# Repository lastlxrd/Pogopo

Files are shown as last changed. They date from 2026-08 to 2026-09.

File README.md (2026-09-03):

# Pogopo

*Both Pogopo and PogopoOS are still in the early stages of development.*

[@lastlxrd](https://github.com/lastlxrd) 2026

<p align="center">
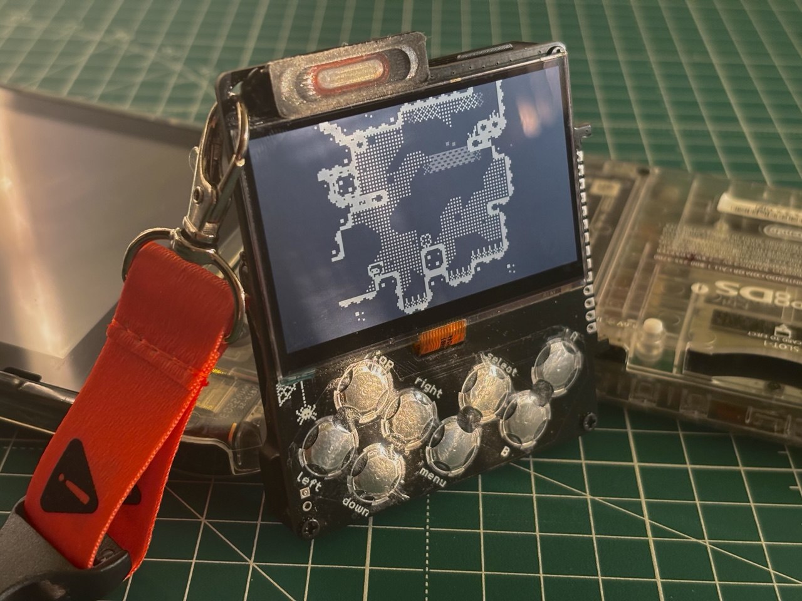
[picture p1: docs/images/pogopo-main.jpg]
Pogopo handheld console
  
</p>

<p align="center">
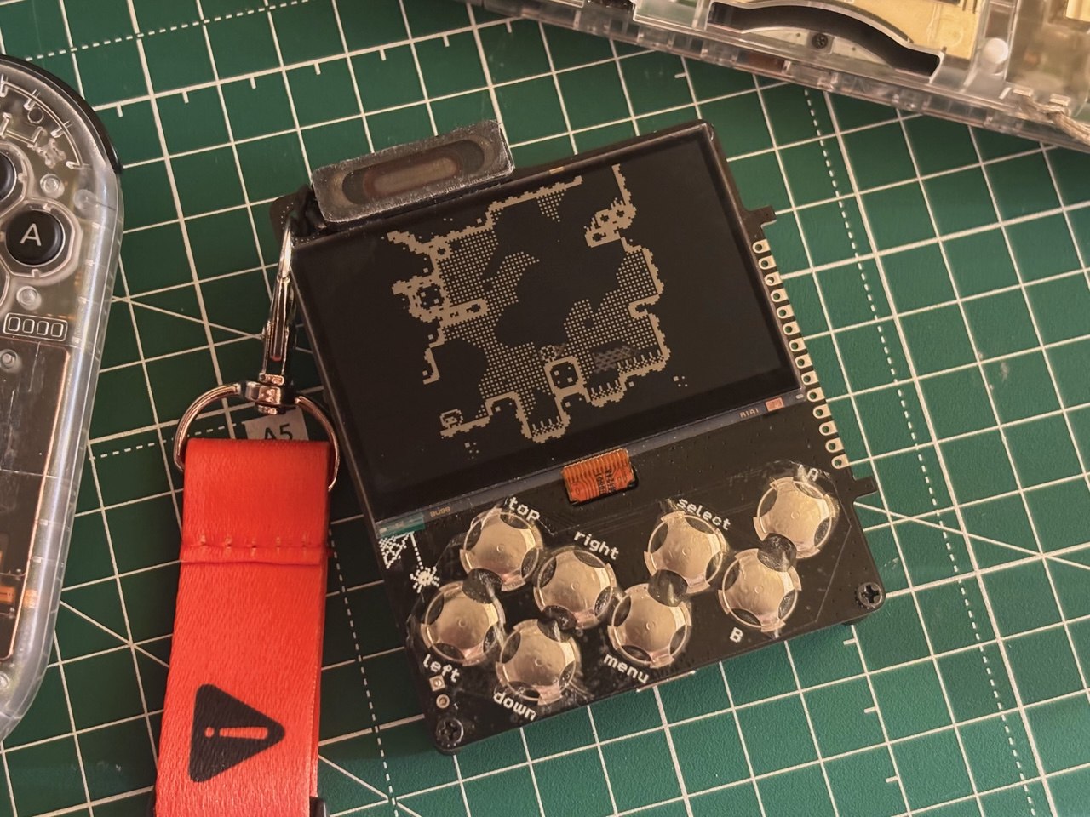
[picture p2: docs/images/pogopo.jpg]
Pogopo top
  
</p>

<p align="center">
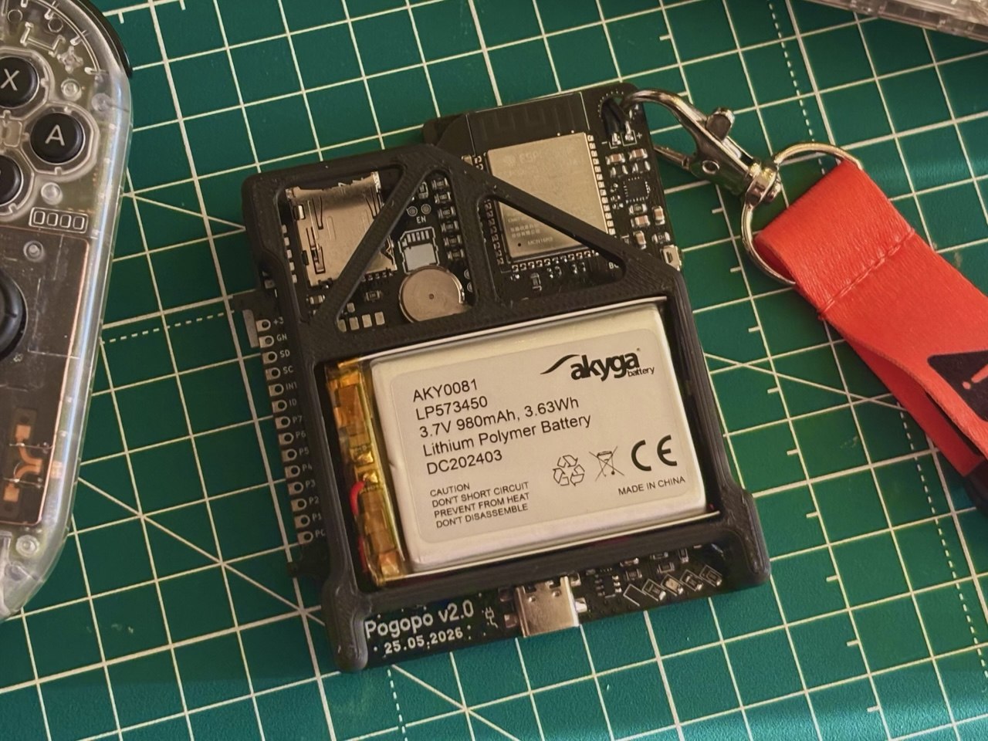
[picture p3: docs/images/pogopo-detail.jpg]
Pogopo hardware detail
  
</p>

## Getting Started

Pogopo is still under active development. More complete documentation will be added as the hardware and software mature.

[Documentation](https://lastlxrd.github.io/Pogopo/)
[FAQ](https://lastlxrd.github.io/Pogopo/faq/)

## Project Summary

Pogopo is a custom hand-built handheld console based on the ESP32-S3. It combines a low-power monochrome display, physical controls, audio, motion sensing, removable storage, haptic feedback, and custom power management in one compact device.

The goal is to create a standalone handheld capable of running native applications, utilities, emulators, and custom games through a simple graphical interface. The current device is a working development prototype, with both its hardware and software continuing to evolve.

## Hardware

- ESP32-S3 with 16 MB flash and 8 MB PSRAM
- Sharp LS027B7DH01 400 × 240 Memory LCD
- BMI270 motion sensor
- MAX98357A I2S audio amplifier
- microSD card over 4-bit SDMMC
- TCA9555 GPIO and button expander
- D-pad, A, B, Menu, Start, and Power controls
- Vibration motor
- Rechargeable battery
- Onboard charging and power management
- Custom PCB and 3D-printed enclosure

## PogopoOS

PogopoOS is the custom operating system and application platform developed specifically for the Pogopo console.

- ESP-IDF-based firmware
- Graphical launcher and application framework
- Reusable display, input, audio, storage, and sensor drivers
- Native I2S audio and WAV playback
- Motion sensing and visualization tools
- microSD file access
- Persistent settings
- Power quick menu and clean LCD shutdown
- Haptic feedback
- Native Game Boy emulation
- Full-speed Game Boy CPU execution
- Approximately 30 FPS LCD presentation
- Four-shade ordered dithering
- Fixed-rate Game Boy audio
- ROM loading from microSD
- Experimental PDX and Lua game runtime

Game ROMs and third-party game files are not included in this repository.

## Development

Pogopo and PogopoOS are developed through small tested milestones. Commit messages contain short summaries of individual changes, while longer technical notes are stored in [`docs/history/`](docs/history/).

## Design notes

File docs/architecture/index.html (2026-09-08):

Skip to content

pogopodocumentation Search docs/ (https://github.com/lastlxrd/Pogopo)

A small, evolving reference for the pogopo hardware and pogopoOS firmware.

System

# Architecture

PogopoOS separates board-specific communication from reusable services and application behavior. The goal is a small set of understandable layers, not documentation for every source file.

## Logical layers

Applications sit at the top of the system and depend on PogopoOS rather than individual chips. The launcher, settings, diagnostics, Game Boy emulator, and PogoDate runtime all enter through the same application lifecycle, so opening an app, suspending it behind the quick menu, and returning Home follow one path.

PogopoOS owns that lifecycle and gives the active application access to graphics, input, audio, storage, motion, haptics, power, and settings. Those services translate useful actions such as reading a button or presenting a frame into driver operations. Pin mappings and bus details remain below the service boundary, where SPI, I²C, I²S, SDMMC, ADC, and GPIO code communicate with the physical board.

This direction is deliberate: an application can use a device capability without reconfiguring the hardware behind it. It also keeps shutdown, save flushing, display clearing, and system overlays under one owner.

## Task and core organization

FreeRTOS work is separated by latency and ownership. The current Game Boy path runs emulation and input on Core 1. Core 0 handles fixed-clock I²S output, decoupled APU generation, motion and power services, VCOM maintenance, and the lower-priority PogopoOS UI/display loop.

This split is a performance decision for the current firmware, not a permanent ABI. Changes are validated with serial timing, underrun, heap, cache, and I²C diagnostics.

## Typical data flow

A button sample begins at the TCA9555, passes through the input service, and reaches only the active application. Drawing moves in the opposite direction: an application writes to the shared 1-bit canvas, then the display driver sends changed rows or a complete frame to the Sharp LCD.

Game Boy audio is generated by MiniGB APU into an internal ring buffer and consumed by a fixed-rate I²S task connected to the MAX98357A. Power-off is coordinated in the same way: the Power service starts the overlay, waits for pending saves, clears the physical display, and only then asks the BQ24295 to enter ship mode.

pogopo documentation ·

## On this page

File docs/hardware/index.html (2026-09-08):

Skip to content

pogopodocumentation Search docs/ (https://github.com/lastlxrd/Pogopo)

A small, evolving reference for the pogopo hardware and pogopoOS firmware.

System

# Hardware

pogopo is built around a custom ESP32-S3 PCB with a 400 × 240 monochrome display, physical controls, audio, storage, motion sensing, haptics, and battery management.

## System overview

The dual-core ESP32-S3 is paired with 16 MB of flash and 8 MB of Octal PSRAM. A Sharp LS027B7DH01 Memory LCD provides the 400 × 240 monochrome display, while a four-bit SDMMC bus connects removable storage without sharing the display’s SPI path.

Front controls arrive through a TCA9555 I/O expander. Motion data comes from a BMI270, audio leaves the MCU over I²S to a MAX98357A amplifier, and a BQ24295 manages charging and the power path. These choices keep the board compact while giving firmware direct control over timing-critical work.

## Core components

### ESP32-S3

The MCU runs PogopoOS, renders the interface, coordinates every peripheral, and hosts the Game Boy and PogoDate runtimes. GPIO, SPI, I²C, I²S, SDMMC, and ADC are all available directly from the chip, while FreeRTOS distributes time-sensitive work across both cores. It was chosen because it combines those interfaces with external-memory support and a mature ESP-IDF stack in one compact part.

### Sharp LS027B7DH01 Memory LCD

The 400 × 240 panel displays the launcher, applications, games, diagnostics, and shutdown animation through SPI2 at 14 MHz. PogopoOS keeps a 12 KB 1-bit framebuffer, transfers only dirty rows when practical, and maintains VCOM in a dedicated task. The panel was chosen for its sharp monochrome image and its ability to retain static pixels without continuous full-screen refresh.

### BMI270

The six-axis IMU reports acceleration and angular rate for diagnostics and motion-aware applications. It shares the I²C bus at address 0x68 and has a dedicated interrupt on GPIO18. This provides a compact motion input without consuming the GPIOs reserved for controls, display, storage, and audio.

### MAX98357A audio

The MAX98357A converts the firmware’s PCM stream into amplified speaker output. DATA, BCLK, and LRCK connect directly to the ESP32-S3 I²S peripheral, and the Game Boy path runs at a fixed 32,768 Hz. A digital amplifier keeps sample timing under firmware control and avoids a separate analog DAC stage.

### microSD storage

The microSD card holds ROMs, audio, Playdate packages, and other user content through ESP-IDF’s FAT filesystem. It uses a four-bit SDMMC connection on D0–D3, CLK, and CMD rather than a basic SPI link. That wider bus improves bulk transfer speed and leaves the display bus independent.

### TCA9555 and controls

The TCA9555 reads the D-pad, A, B, Start, and Menu as one active-low byte over I²C at 0x20, with its interrupt connected to GPIO21. A failed read is treated as a released sample so a bus fault cannot leave a control stuck. The expander saves eight direct MCU pins and lets firmware capture the entire front-panel state in one transaction.

### Haptics

The vibration motor is driven from GPIO3 through the board’s output stage. It gives UI and gameplay actions a short physical response, which is useful when another sound or screen effect would be distracting.

### Battery and power management

The BQ24295 at I²C address 0x6B manages charging and the power path. Firmware reads its charge and fault state, measures the battery through a gated ADC on GPIO1, handles the separate Power input on GPIO17, and requests ship mode only after saves are flushed and the LCD is cleared. This gives PogopoOS a controlled shutdown path instead of relying on an abrupt battery disconnect.

## Custom PCB

The custom board integrates the ESP32-S3, display connection, SDMMC bus, I²C peripherals, digital audio, controls, haptics, and power-management signals used by PogopoOS. Bring-up diagnostics probe the TCA9555, BMI270, and BQ24295 and print their register state to the serial monitor.

## Enclosure

The enclosure is designed as a compact handheld around the display, physical controls, custom PCB, and a right-side expansion area. Mechanical module retention and the final external connector arrangement remain work in progress.

pogopo documentation ·

## On this page

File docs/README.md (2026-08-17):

# pogopo technical documentation

This folder is a dependency-free static documentation site for GitHub Pages.
It is designed to live at `pogopoOS/docs` without changing the firmware project
layout or build.

The top-level pages are Overview, Hardware, Modularity, PogopoOS, Architecture,
Engineering, Gallery, FAQ, and Development. The former `getting-started` and
`games` URLs are retained only as compatibility redirects.

## Local preview

From the repository root, run:

```powershell
python -m http.server 8000
```

Then open `http://localhost:8000/docs/`.

## GitHub Pages

Commit the `docs` folder, open the repository **Settings → Pages**, choose
**Deploy from a branch**, select the `main` branch and the `/docs` folder, then
save. The site will be published under the repository's GitHub Pages URL.

## Editing

Every page is plain HTML. Shared appearance is in `assets/styles.css`.
`assets/theme.js` restores the light/dark preference before the page is painted,
while `assets/app.js` generates the navigation, page table of contents, search,
theme button, mobile menu, and previous/next links. The frog remains the
original transparent PNG; its light-mode outline is generated at display time.

Hardware photographs and final architecture diagrams are intentionally marked
as TODO until verified project assets are added. UI captures in
`assets/gallery` come from the current firmware project.

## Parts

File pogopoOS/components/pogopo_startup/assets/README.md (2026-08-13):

# Intro and Power Outro animation assets

`../startup_frames.bin` contains 25 full-screen 400 x 240 monochrome frames.
Every frame is 12,000 bytes in the Sharp display's native LSB-first, white=1
framebuffer format.

`../outro_frames.bin` contains 24 transparent overlays. Source frame 1 is
omitted because it is a full-white frame. Each 24,000-byte frame
stores a 12,000-byte color plane followed by a 12,000-byte opacity mask. This
preserves the live menu/game image wherever the Aseprite frame is transparent.

They are packed directly from the supplied GIFs with:

```powershell
python tools\pack_sharpbit_gif.py `
  path\to\pogopoINTRO.gif `
  components\pogopo_startup\startup_frames.bin

python tools\pack_aseprite_overlay.py `
  path\to\pogopoOUTRO.aseprite `
  components\pogopo_startup\outro_frames.bin `
  --start-frame 2 --frames 24
```

The binary intentionally lives at the component root. This keeps the generated
ESP-IDF linker symbols stable on Windows and across ESP-IDF versions.

Both packers require exact black/white pixels. The Outro packer reads the true
Aseprite alpha channel instead of flattening transparent pixels to GIF black.

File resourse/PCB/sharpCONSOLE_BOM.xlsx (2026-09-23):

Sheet: BOM для закупки
№ | Тип | Номінал / Part | Корпус / Footprint | К-сть | Позначення на платі | Примітка | Datasheet
1 | Розʼєм / джампер | Conn_01x02_Pin | PinHeader_1x02_P2.00mm_Vertical | 1 | audio_socket1
2 | Конденсатор | 0.1uF або менше | 0805 / 2012 metric | 1 | C3
3 | Конденсатор | 0.1uF | 0805 / 2012 metric | 20 | C4,C5,C7,C8,C12,C17,C33,C36,C41,C42,C43,C44,C45,C46,C47,C48,C49,C50,C51,C53
4 | Конденсатор | 22uF | 0805 / 2012 metric | 9 | C6,C20,C21,C22,C23,C37,C38,C39,C40
5 | Конденсатор | 1uF | 0805 / 2012 metric | 2 | C10,C30
6 | Конденсатор | 10uF | 0805 / 2012 metric | 9 | C11,C18,C19,C26,C27,C32,C34,C35,C52
8 | Конденсатор | 220pF | 0805 / 2012 metric | 2 | C14,C15
10 | Конденсатор | 47nF | 0805 / 2012 metric | 1 | C28
11 | Конденсатор | 4.7uF | 0805 / 2012 metric | 1 | C29
12 | Конденсатор | 20uF | 0805 / 2012 metric | 1 | C31
13 | LED / діод | D | LED 0805 / 2012 | 1 | D1
14 | Діод | SS14 | SMA diode package | 1 | D2 |  | https://www.vishay.com/docs/88746/ss12.pdf
15 | Діод | MAX98357A | TQFN-16-1EP_3x3mm_P0.5mm_EP1.23x1.23mm | 1 | DAC1 |  | https://www.analog.com/media/en/technical-documentation/data-sheets/MAX98357A-MAX98357B.pdf
17 | Мікросхема / модуль | ESP32-S3-WROOM-1 | ESP32-S3-WROOM-1 | 1 | ESP2 |  | https://www.espressif.com/sites/default/files/documentation/esp32-s3-wroom-1_wroom-1u_datasheet_en.pdf
18 | Ferrite bead | 600 | 0805 / 2012 metric | 2 | FB2,FB3
19 | Розʼєм / джампер | battery | PinHeader_1x02_P2.54mm_Vertical | 1 | J1
20 | Розʼєм / джампер | Conn_01x06_Pin | pad_6pin | 1 | J2
21 | Розʼєм / джампер | vibro+ | TestPoint_Pad_1.5x1.5mm | 1 | J4
22 | Розʼєм / джампер | vibro- | TestPoint_Pad_1.5x1.5mm | 1 | J5
23 | Розʼєм / джампер | Conn_01x14_Pin | pads rp2040 | 1 | J6
24 | Розʼєм / джампер | Conn_01x10_Pin | pad_10pin | 1 | J7
25 | Розʼєм / джампер | Conn_01x10_Pin | TE_1-1734839-0_1x10-1MP_P0.5mm_Horizontal | 1 | J9
26 | Розʼєм / джампер | SolderJumper_3_Open | SolderJumper-3_P1.3mm_Open_RoundedPad1.0x1.5mm | 2 | JP1,JP2
27 | Індуктивність | 1.5uH | L_Chilisin_BMRA00050530 | 2 | L1,L3
28 | Індуктивність | 2.2uH | L_Chilisin_BMRA00050530 | 1 | L2
29 | Транзистор / MOSFET | NPN | SOT-23-3 | 1 | Q1 |  | https://ngspice.sourceforge.io/docs/ngspice-html-manual/manual.xhtml#cha_BJTs
30 | Транзистор / MOSFET | NMOS | SOT-23 | 2 | Q2,Q3 |  | https://ngspice.sourceforge.io/docs/ngspice-html-manual/manual.xhtml#cha_MOSFETs
31 | Резистор | 0R | 0805 / 2012 metric | 1 | R1
32 | Резистор | 5.1k | 0805 / 2012 metric | 2 | R2,R3
33 | Резистор | 10k | 0805 / 2012 metric | 27 | R4,R5,R9,R10,R11,R12,R13,R17,R24,R25,R26,R29,R30,R31,R42,R73,R76,R78,R80,R82,R84,R86,R88,R90,R91,R93,R94
34 | Резистор | 33R | 0805 / 2012 metric | 1 | R14
35 | Резистор | 100k | 0805 / 2012 metric | 5 | R15,R16,R33,R36,R71
36 | Резистор | 300R | 0805 / 2012 metric | 4 | R18,R27,R28,R72
37 | Резистор | 1M | 0805 / 2012 metric | 4 | R19,R34,R37,R40
39 | Резистор | 2k2 | 0805 / 2012 metric | 1 | R23
40 | Резистор | 180k | 0805 / 2012 metric | 2 | R35,R39
41 | Резистор | 1.6M | 0805 / 2012 metric | 1 | R38
42 | Резистор | 0 | 0402 / 1005 metric | 23 | R43,R44,R45,R46,R47,R48,R52,R53,R54,R55,R56,R57,R58,R59,R60,R61,R62,R63,R64,R70,R96,R97,R98
44 | Резистор | 1k | 0805 / 2012 metric | 8 | R74,R75,R77,R79,R81,R83,R85,R87
45 | Розʼєм / джампер | Micro_SD_Card | microSD_HC_Hirose_DM3AT-SF-PEJM5 | 1 | SD1 |  | https://www.we-online.com/components/products/datasheet/693072010801.pdf
46 | Кнопка / перемикач | top | SW_Dome_10mm | 1 | SW1
47 | Кнопка / перемикач | down | SW_Dome_10mm | 1 | SW2
48 | Кнопка / перемикач | right | SW_Dome_10mm | 1 | SW3
49 | Кнопка / перемикач | SW_SPST | SW_DIP_SPSTx01_Slide_Copal_CVS-01xB_W5.9mm_P1mm | 1 | SW4
50 | Кнопка / перемикач | left | SW_Dome_10mm | 1 | SW5
51 | Кнопка / перемикач | SW_Push | SW_SPST_B3U-3000P | 1 | SW6
52 | Кнопка / перемикач | B | SW_Dome_10mm | 1 | SW7
53 | Кнопка / перемикач | A | SW_Dome_10mm | 1 | SW8
54 | Кнопка / перемикач | menu | SW_Dome_10mm | 1 | SW9
55 | Кнопка / перемикач | start | SW_Dome_10mm | 1 | SW10
56 | Test point | TestPoint | TestPoint_Pad_1.5x1.5mm | 1 | TP1
57 | Test point | TestPoint | TestPoint_Pad_D1.0mm | 6 | TP3,TP4,TP5,TP6,TP9,TP10
58 | Test point | TestPoint | TestPoint_Pad_1.0x1.0mm | 2 | TP7,TP8
59 | Мікросхема / модуль | TPS63020 | TPS63020 | 2 | U1,U5 |  | http://www.ti.com/lit/ds/symlink/tps63000.pdf
60 | Мікросхема / модуль | BQ24295RGER | IC_BQ24295RGER | 1 | U2
61 | Мікросхема / модуль | USBLC6-2SC6 | SOT-23-6 | 1 | U3 |  | https://www.st.com/resource/en/datasheet/usblc6-2.pdf
62 | Мікросхема / модуль | TS3USB221A | QFN-10-RSE | 1 | U4
63 | Мікросхема / модуль | BMI270 | XDCR_BMI270 | 1 | U6
64 | Мікросхема / модуль | TCA9555PWR | TSSOP-24_4.4x7.8mm_P0.65mm | 1 | U7 |  | http://www.ti.com/lit/ds/symlink/tca9555.pdf
65 | Мікросхема / модуль | USB_C_Receptacle_USB2.0_16P | USB_C_Receptacle_GCT_USB4110 | 1 | USBC1 |  | https://www.usb.org/sites/default/files/documents/usb_type-c.zip

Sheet: DNP не паяти
№ | Тип | Номінал / Part | Корпус / Footprint | К-сть | Позначення на платі | Примітка | Datasheet
7 | Конденсатор | 10uF | 0805 / 2012 metric | 2 | C13,C24 | Excluded from BOM/board у KiCad
9 | Конденсатор | 0.1uF | 0805 / 2012 metric | 2 | C16,C25 | Excluded from BOM/board у KiCad
16 | Розʼєм / джампер | Conn_01x40_Pin | Hirose_FH12-40S-0.5SH_1x40-1MP_P0.50mm_Horizontal | 1 | display2 | Excluded from BOM/board у KiCad
38 | Резистор | 10k | 0805 / 2012 metric | 3 | R20,R21,R22 | Excluded from BOM/board у KiCad
43 | Резистор | 0 | 0402 / 1005 metric | 5 | R65,R66,R67,R68,R69 | Excluded from BOM/board у KiCad

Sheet: Зведення
sharpCONSOLE — очищений BOM з KiCad
Параметр | Значення |  | Що я поправив
Рядків у KiCad CSV | 65 |  | 1 | Залишив зрозумілі колонки: тип, номінал, корпус, кількість, позначення.
Активних позицій BOM | 60 |  | 2 | DNP/Excluded виніс окремим листом, щоб випадково не закупити/не паяти.
Активних компонентів, шт. | 175 |  | 3 | Footprint скоротив до нормального вигляду, але Raw KiCad залишив без змін.
DNP / виключено позицій | 5 |  | 4 | Datasheet лишив лише там, де був реальний URL.
DNP компонентів, шт. | 13 |  | 5 | У “BOM для закупки” тільки активні компоненти.
Тип компонента | Позицій у BOM | Загальна к-сть
Ferrite bead | 1 | 2
LED / діод | 1 | 1
Test point | 3 | 9
Індуктивність | 2 | 3
Діод | 2 | 2
Кнопка / перемикач | 10 | 10
Конденсатор | 9 | 46
Мікросхема / модуль | 8 | 9
Резистор | 12 | 79
Розʼєм / джампер | 10 | 11
Транзистор / MOSFET | 2 | 3

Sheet: Raw KiCad
Reference | Qty | Value | DNP | Exclude from BOM | Exclude from Board | Footprint | Datasheet
audio_socket1 | 1 | Conn_01x02_Pin |  |  |  | Connector_PinHeader_2.00mm:PinHeader_1x02_P2.00mm_Vertical | ~
C3 | 1 | 0.1uF або менше |  |  |  | Capacitor_SMD:C_0805_2012Metric | ~
C4,C5,C7,C8,C12,C17,C33,C36,C41,C42,C43,C44,C45,C46,C47,C48,C49,C50,C51,C53 | 20 | 0.1uF |  |  |  | Capacitor_SMD:C_0805_2012Metric | ~
C6,C20,C21,C22,C23,C37,C38,C39,C40 | 9 | 22uF |  |  |  | Capacitor_SMD:C_0805_2012Metric | ~
C10,C30 | 2 | 1uF |  |  |  | Capacitor_SMD:C_0805_2012Metric | ~
C11,C18,C19,C26,C27,C32,C34,C35,C52 | 9 | 10uF |  |  |  | Capacitor_SMD:C_0805_2012Metric | ~
C13,C24 | 2 | 10uF | DNP | Excluded from BOM | Excluded from board | Capacitor_SMD:C_0805_2012Metric | ~
C14,C15 | 2 | 220pF |  |  |  | Capacitor_SMD:C_0805_2012Metric | ~
C16,C25 | 2 | 0.1uF | DNP | Excluded from BOM | Excluded from board | Capacitor_SMD:C_0805_2012Metric | ~
C28 | 1 | 47nF |  |  |  | Capacitor_SMD:C_0805_2012Metric | ~
C29 | 1 | 4.7uF |  |  |  | Capacitor_SMD:C_0805_2012Metric | ~
C31 | 1 | 20uF |  |  |  | Capacitor_SMD:C_0805_2012Metric | ~
D1 | 1 | D |  |  |  | LED_SMD:LED_0805_2012Metric | ~
D2 | 1 | SS14 |  |  |  | Diode_SMD:D_SMA | https://www.vishay.com/docs/88746/ss12.pdf
DAC1 | 1 | MAX98357A |  |  |  | Package_DFN_QFN:TQFN-16-1EP_3x3mm_P0.5mm_EP1.23x1.23mm | https://www.analog.com/media/en/technical-documentation/data-sheets/MAX98357A-MAX98357B.pdf
display2 | 1 | Conn_01x40_Pin | DNP | Excluded from BOM | Excluded from board | Connector_FFC-FPC:Hirose_FH12-40S-0.5SH_1x40-1MP_P0.50mm_Horizontal | ~
ESP2 | 1 | ESP32-S3-WROOM-1 |  |  |  | RF_Module:ESP32-S3-WROOM-1 | https://www.espressif.com/sites/default/files/documentation/esp32-s3-wroom-1_wroom-1u_datasheet_en.pdf
FB2,FB3 | 2 | 600 |  |  |  | Resistor_SMD:R_0805_2012Metric | ~
J1 | 1 | battery |  |  |  | Connector_PinHeader_2.54mm:PinHeader_1x02_P2.54mm_Vertical | ~
J2 | 1 | Conn_01x06_Pin |  |  |  | Library:pad_6pin | ~
J4 | 1 | vibro+ |  |  |  | TestPoint:TestPoint_Pad_1.5x1.5mm | ~
J5 | 1 | vibro- |  |  |  | TestPoint:TestPoint_Pad_1.5x1.5mm | ~
J6 | 1 | Conn_01x14_Pin |  |  |  | Connector_PinSocket_2.54mm:pads rp2040 | ~
J7 | 1 | Conn_01x10_Pin |  |  |  | Library:pad_10pin | ~
J9 | 1 | Conn_01x10_Pin |  |  |  | Connector_FFC-FPC:TE_1-1734839-0_1x10-1MP_P0.5mm_Horizontal | ~
JP1,JP2 | 2 | SolderJumper_3_Open |  |  |  | Jumper:SolderJumper-3_P1.3mm_Open_RoundedPad1.0x1.5mm | ~
L1,L3 | 2 | 1.5uH |  |  |  | Inductor_SMD:L_Chilisin_BMRA00050530 | ~
L2 | 1 | 2.2uH |  |  |  | Inductor_SMD:L_Chilisin_BMRA00050530 | ~
Q1 | 1 | NPN |  |  |  | Package_TO_SOT_SMD:SOT-23-3 | https://ngspice.sourceforge.io/docs/ngspice-html-manual/manual.xhtml#cha_BJTs
Q2,Q3 | 2 | NMOS |  |  |  | Package_TO_SOT_SMD:SOT-23 | https://ngspice.sourceforge.io/docs/ngspice-html-manual/manual.xhtml#cha_MOSFETs
R1 | 1 | 0R |  |  |  | Resistor_SMD:R_0805_2012Metric | ~
R2,R3 | 2 | 5.1k |  |  |  | Resistor_SMD:R_0805_2012Metric | ~
R4,R5,R9,R10,R11,R12,R13,R17,R24,R25,R26,R29,R30,R31,R42,R73,R76,R78,R80,R82,R84,R86,R88,R90,R91,R93,R94 | 27 | 10k |  |  |  | Resistor_SMD:R_0805_2012Metric | ~
R14 | 1 | 33R |  |  |  | Resistor_SMD:R_0805_2012Metric | ~
R15,R16,R33,R36,R71 | 5 | 100k |  |  |  | Resistor_SMD:R_0805_2012Metric | ~
R18,R27,R28,R72 | 4 | 300R |  |  |  | Resistor_SMD:R_0805_2012Metric | ~
R19,R34,R37,R40 | 4 | 1M |  |  |  | Resistor_SMD:R_0805_2012Metric | ~
R20,R21,R22 | 3 | 10k | DNP | Excluded from BOM | Excluded from board | Resistor_SMD:R_0805_2012Metric | ~
R23 | 1 | 2k2 |  |  |  | Resistor_SMD:R_0805_2012Metric | ~
R35,R39 | 2 | 180k |  |  |  | Resistor_SMD:R_0805_2012Metric | ~
R38 | 1 | 1.6M |  |  |  | Resistor_SMD:R_0805_2012Metric | ~
R43,R44,R45,R46,R47,R48,R52,R53,R54,R55,R56,R57,R58,R59,R60,R61,R62,R63,R64,R70,R96,R97,R98 | 23 | 0 |  |  |  | Resistor_SMD:R_0402_1005Metric | ~
R65,R66,R67,R68,R69 | 5 | 0 | DNP | Excluded from BOM | Excluded from board | Resistor_SMD:R_0402_1005Metric | ~
R74,R75,R77,R79,R81,R83,R85,R87 | 8 | 1k |  |  |  | Resistor_SMD:R_0805_2012Metric | ~
SD1 | 1 | Micro_SD_Card |  |  |  | Connector_Card:microSD_HC_Hirose_DM3AT-SF-PEJM5 | https://www.we-online.com/components/products/datasheet/693072010801.pdf
SW1 | 1 | top |  |  |  | dome switch 10mm:SW_Dome_10mm | ~
SW2 | 1 | down |  |  |  | dome switch 10mm:SW_Dome_10mm | ~
SW3 | 1 | right |  |  |  | dome switch 10mm:SW_Dome_10mm | ~
SW4 | 1 | SW_SPST |  |  |  | Button_Switch_SMD:SW_DIP_SPSTx01_Slide_Copal_CVS-01xB_W5.9mm_P1mm | ~
SW5 | 1 | left |  |  |  | dome switch 10mm:SW_Dome_10mm | ~
SW6 | 1 | SW_Push |  |  |  | Button_Switch_SMD:SW_SPST_B3U-3000P | ~
SW7 | 1 | B |  |  |  | dome switch 10mm:SW_Dome_10mm | ~
SW8 | 1 | A |  |  |  | dome switch 10mm:SW_Dome_10mm | ~
SW9 | 1 | menu |  |  |  | dome switch 10mm:SW_Dome_10mm | ~
SW10 | 1 | start |  |  |  | dome switch 10mm:SW_Dome_10mm | ~
TP1 | 1 | TestPoint |  |  |  | TestPoint:TestPoint_Pad_1.5x1.5mm | ~
TP3,TP4,TP5,TP6,TP9,TP10 | 6 | TestPoint |  |  |  | TestPoint:TestPoint_Pad_D1.0mm | ~
TP7,TP8 | 2 | TestPoint |  |  |  | TestPoint:TestPoint_Pad_1.0x1.0mm | ~
U1,U5 | 2 | TPS63020 |  |  |  | TPS63020:TPS63020 | http://www.ti.com/lit/ds/symlink/tps63000.pdf
U2 | 1 | BQ24295RGER |  |  |  | BQ24295RGER:IC_BQ24295RGER
U3 | 1 | USBLC6-2SC6 |  |  |  | Package_TO_SOT_SMD:SOT-23-6 | https://www.st.com/resource/en/datasheet/usblc6-2.pdf
U4 | 1 | TS3USB221A |  |  |  | TS3USB221A:QFN-10-RSE
U6 | 1 | BMI270 |  |  |  | BMI270:XDCR_BMI270
U7 | 1 | TCA9555PWR |  |  |  | Package_SO:TSSOP-24_4.4x7.8mm_P0.65mm | http://www.ti.com/lit/ds/symlink/tca9555.pdf
USBC1 | 1 | USB_C_Receptacle_USB2.0_16P |  |  |  | Connector_USB:USB_C_Receptacle_GCT_USB4110 | https://www.usb.org/sites/default/files/documents/usb_type-c.zip

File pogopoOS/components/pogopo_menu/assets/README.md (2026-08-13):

# Menu assets

`../menu_assets.bin` contains the four supplied 1-bit menu animations and six
bitmap-font faces generated from `pogofont-Regular.otf` and
`pogofont-RegularItalic.otf`.

The binary uses stable `_binary_menu_assets_bin_start/end` linker symbols and
is already generated; Pillow is not required for a normal ESP-IDF build.

To regenerate it from the original `docs` directory:

```powershell
python tools\pack_menu_assets.py `
  path\to\docs `
  components\pogopo_menu\menu_assets.bin `
  components\pogopo_menu\src\menu_data_generated.h
```

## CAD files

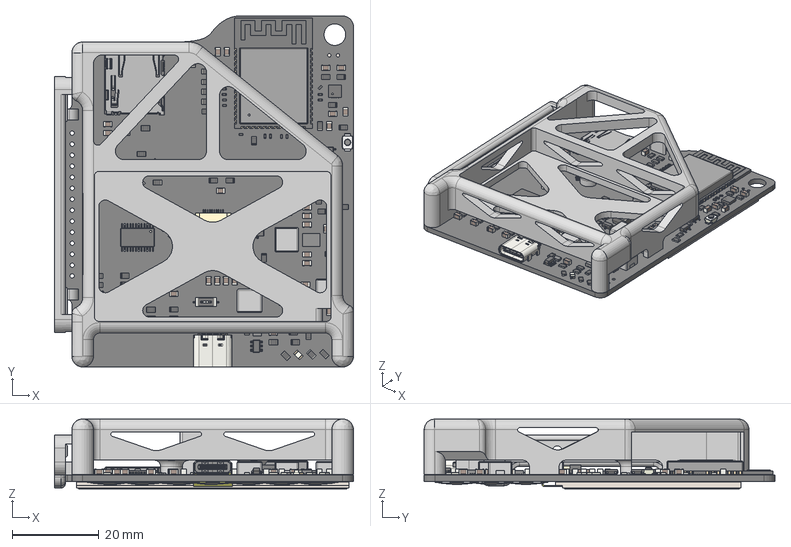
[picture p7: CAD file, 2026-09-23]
resourse/CAD/pogopo.step
69.0 x 81.0 x 16.1 mm
R_0805_2012Metric x 58
C_0805_2012Metric x 46
R_0402_1005Metric x 23
SOT-23 x 2
BMI270
sharpCONSOLE 1.31.1 x 3
TPS63020 x 2
SOT-23-3
TQFN-16-1EP_3x3mm_P0.5mm_EP1.6x1.6mm
lock
pins
Glass
Active area
Flat cable
TSSOP-24_4.4x7.8mm_P0.65mm
TS3USB221A
BQ24295RGER
LED_0805_2012Metric
microSD_HC_Hirose_DM3AT-SF-PEJM5
SOT-23-6
ESP32-S3-WROOM-1
SW_DIP_SPSTx01_Slide_Copal_CVS-01xB_W5.9mm_P1mm
D_SMA
USB_C_Receptacle_GCT_USB4105-xx-A_16P_TopMnt_Horizontal
SW_SPST_B3U-1000P
Keystone10mmDiaDomePB v2 x 8
sharpCONSOLE_PCB
plate
pogogrip

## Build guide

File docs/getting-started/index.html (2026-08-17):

Skip to content

pogopodocumentation Search docs/ (https://github.com/lastlxrd/pogopoOS)

A small, evolving reference for the pogopo hardware and pogopoOS firmware.

Compatibility page

# Setup moved

Build, flash, SD-card setup, and the current project status now live together on the Development page.

Open Development →

pogopo documentation ·

## On this page

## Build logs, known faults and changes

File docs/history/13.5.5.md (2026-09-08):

# STEP13.5.5

- Fixed page-title spacing and forced a fresh stylesheet load.
- Enlarged console and PCB media in the Gallery.
- Preserved transparent PCB backgrounds in both themes.

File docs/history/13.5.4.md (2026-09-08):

# STEP13.5.4

- Reworked the documentation into a cleaner, prose-led layout.
- Added current Pogopo hardware, PCB, and firmware media to the Gallery.
- Fixed heading spacing across desktop and mobile pages.

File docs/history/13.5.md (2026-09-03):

# STEP13.5

- Let PogoDate borrow Game Boy's idle internal-RAM arena for its hot framebuffer.
- Restore the Game Boy ROM arena automatically after leaving a Playdate game.
- Keep the existing byte blit and watchdog-safe scheduling fixes.

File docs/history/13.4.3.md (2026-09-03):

# STEP13.4.3

- Expanded eight PDI/PDT pixels per blit operation for faster sprite drawing.
- Removed two unused-variable build warnings from lazy sound loading.
- Guaranteed a scheduler yield when an emulator frame misses its deadline.

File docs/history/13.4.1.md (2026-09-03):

# STEP13.4.1

- Cached small `main.pdz` archives in PSRAM for faster module imports.
- Deferred short sound decoding until first playback.
- Added `game`, `spr`, `timer`, `ft`, and `other` frame profiling.
- Cleaned obsolete documentation redirects and merge notes.

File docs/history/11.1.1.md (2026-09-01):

# STEP11.1.1 — Celeste clamp compile fix

## Before

Celeste failed to compile because `std::clamp()` received mixed `float` and `double` argument types.

## Changes

The clamp value and limits were explicitly converted to `lua_Number`.

## Result

The project compiled successfully, with no runtime behavior changes.

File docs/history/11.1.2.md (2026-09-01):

# STEP11.1.2 — Celeste performance fix

## Before

Celeste worked, but each frame took about 190 ms and the screen appeared to update at only 1–2 FPS.

## Changes

The catch-up scheduler was removed, framebuffer scaling was simplified and sprite, image and final blit paths were optimized.

## Result

After building and flashing, Celeste still ran at roughly 5 FPS and remained effectively unplayable.

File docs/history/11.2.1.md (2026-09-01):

# STEP11.2.1 — SD PDX launcher stack and hot-mount fix

## Before

Opening the SD Playdate browser with a valid PDX package caused a stack overflow and restarted the menu.

## Changes

The temporary PDZ index was moved to heap/PSRAM, package scanning was simplified and SD hot-mount retry support was added. :contentReference[oaicite:0]{index=0}

## Result

After building and flashing, the browser opened and detected Celeste, but launching it became stuck indefinitely on `LOADING GAME: CELESTE CLASSIC` with the same log sequence repeating.

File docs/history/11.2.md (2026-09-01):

# STEP11.2 — SD Playdate PDX/PDZ loader

## Before

Celeste ran at about 30 FPS, but Playdate games were still embedded in the firmware instead of being loaded from the SD card.

## Changes

An SD package browser and loader for `.pdx` folders, `main.pdz`, Playdate images and original audio assets were added. :contentReference[oaicite:0]{index=0}

## Result

After building and flashing, the browser reported no mounted SD card without a card inserted, but with the card present it froze, triggered vibration and restarted the menu when opening the Playdate games folder.

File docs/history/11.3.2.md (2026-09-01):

# STEP11.3.2 — Playdate button-name compatibility

## Before

Onebit Frogger passed `drawRotated()` but stopped because its `btnp()` helper passed string button names instead of numeric Playdate masks.

## Changes

String button names, common prefixes, `buttonJustReleased()` and `getButtonState()` compatibility were added.

## Result

After building and flashing, Frogger still stopped with the same string `btnp()` argument error, while forcing Celeste to 50 FPS made its frame-based gameplay run too fast and did not remove occasional animation stutter.

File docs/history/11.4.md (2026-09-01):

# STEP11.4 — Broader PDX compatibility and smooth frame pacing

## Before

Celeste worked from SD, but forced 50 FPS made the game run too fast and Onebit Frogger still exposed missing Playdate compatibility.

## Changes

Frogger compatibility, cached sound effects, incremental Lua garbage collection and more accurate frame pacing were added, while Celeste logic was restored to its original 30 FPS timing. :contentReference[oaicite:0]{index=0}

## Result

Celeste and Onebit Frogger now appear stable, but compatibility with other PDX packages is still unverified and will require further testing and API fixes.

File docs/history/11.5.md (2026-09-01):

# STEP11.5 — Real PFT fonts and broader Playdate compatibility

## Before

STEP11.4 improved general PDX loading and frame pacing, but Onebit Frogger still used a fallback font and more complex Lua Playdate games exposed additional missing APIs.

## Changes

Real Playdate PFT font parsing and rendering were added together with broader display, timer, sprite, collision, image and audio compatibility required by Onebit Frogger and Godspeed. :contentReference[oaicite:0]{index=0}

## Result

Onebit Frogger now renders its original font correctly and both Frogger and Godspeed complete host runtime tests with zero errors, while native ARM `pdex.bin` packages remain unsupported.

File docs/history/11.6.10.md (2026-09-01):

# STEP11.6.10 — Maze completion and Duel boss-fight polish

## Before

STEP11.6.9 corrected Maze-specific controls and moved its Level Complete frames into the PSRAM pool, but the completion flow still had an accidental START-to-A path and both Maze transitions and Duel boss combat retained visual and collision issues.

## Changes

Maze now disables the START-to-A alias only while it owns input, sparse LevelComplete images render only their real content bounds with a reused composition target, and Duel gains flip-correct scaled sprites, frame-size tracking and swept collision handling. :contentReference[oaicite:0]{index=0}

## Result

Maze keeps pixel-identical Level Complete output while its host regression drops from roughly 2.53 s to 0.31 s, and Duel Of Shadows now renders left-facing movement correctly and avoids the previous boss-fight position jumps and collision ejections.

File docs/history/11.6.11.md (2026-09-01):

# STEP11.6.11 — Lua Playdate synth support

## Before

STEP11.6.10 polished Maze and Duel gameplay, but some Lua PDX packages still failed during startup because `playdate.sound.synth` was missing.

## Changes

`playdate.sound.synth` is now backed by Pogopo's four-voice mixer with managed per-synth voices, waveform generation, note playback, ADSR envelopes, transpose and common Playdate synth controls. :contentReference[oaicite:0]{index=0}

## Result

Lua packages can now create and play independent synth voices without interrupting samples, music, UI audio or other synths, while the existing Maze, Duel, Celeste, Godspeed and Frogger regressions remain stable.

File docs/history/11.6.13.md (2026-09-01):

# STEP11.6.13 — External PDZ load/run for Pulp packages

## Before

STEP11.6.12 completed the Lua crank surface, but Pulp-style packages such as WOOD still stopped on the first logical frame because `playdate.file.load()` was missing.

## Changes

`playdate.file.load()` and `playdate.file.run()` now support deferred external PDZ bytecode loading with optional environments, opcode normalization, returned values, package sandboxing and clean error handling. :contentReference[oaicite:0]{index=0}

## Result

Pulp-style packages can now load and execute standalone data PDZ files at runtime, while the new 20 FPS load/run probe and all existing crank, synth, Maze, Duel, Celeste, Godspeed and Frogger regressions remain stable.

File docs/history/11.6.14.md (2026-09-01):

# STEP11.6.14 — Pulp runtime graphics and audio-clock surface

## Before

STEP11.6.13 added external PDZ load/run support, but Pulp packages could still fail on their first deferred frame when the engine reached cached graphics and sound-clock APIs.

## Changes

PogoDate now implements the Pulp-used `drawPixel()`, class-style image drawing, tiled drawing, graphics clear/inversion and the resettable Playdate sound device clock as generic compatibility APIs. :contentReference[oaicite:0]{index=0}

## Result

The real WOOD package now loads its data and image tables, enters gameplay at its authored 20 FPS and completes a 1800-frame input, rendering and audio stress test with zero errors.

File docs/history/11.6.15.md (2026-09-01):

# STEP11.6.15 — Playdate responder stack and Pulp controls

## Before

STEP11.6.14 let Pulp games load, render and play audio, but global Playdate button callbacks were never reached so physical controls did nothing.

## Changes

Button events now follow Playdate's responder stack from pushed input handlers down to the global `playdate` callbacks, including masking and first-handler behavior, without changing existing polled input or package-specific mappings. :contentReference[oaicite:0]{index=0}

## Result

WOOD now advances through its beach dialog, enters the playable room and responds to D-pad movement while preserving its authored 20 FPS target and passing the existing regression suite.

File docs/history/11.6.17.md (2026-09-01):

# STEP11.6.17 — Playdate game compatibility

## Before

STEP11.6.16 filled the general geometry, JSON and graphics gaps, but many small
2D games could still stop on common sprite queries, tilemap mutation, generated
image helpers or the SDK pathfinder. Those calls sit below bundled CoreLibs and
game frameworks, so one missing leaf could prevent an otherwise compatible Lua
`main.pdz` from reaching its first frame.

## Changes

PogoDate now implements point/line sprite queries with ordered hit metadata,
sprite bounds/copy/stencil/state helpers, mutable tilemaps and merged collision
rects, anchored/cropped/rotated/masked/affine-transformed images, text images,
additional geometry and graphics operations, and an inspectable A* pathfinder
with graphs, nodes, weighted connections and 2D-grid construction. Wall sprites
now use the tilemap's real tile dimensions. The step adds or expands 92 named
Lua methods without package-name or asset-specific workarounds.

## Result

The dedicated game-compatibility regression passes alongside input, crank,
synth, Maze, Duel and WOOD tests. Maze completes 900 logical frames and Duel
1,800 with zero Lua errors. WOOD keeps its authored 20 FPS rate and all eight
captured progression frames remain byte-identical to STEP11.6.16.

This is a much broader base for testing other free Lua/PDZ games, but it is not
full Playdate OS: native `pdex.bin`, networking, microphone, video, extensions
and the complete sound instrument/sequence/modulation stack remain outside this
step. Final LCD, SD, BMI270 and speaker behaviour still requires Pogopo hardware.

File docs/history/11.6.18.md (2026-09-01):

# STEP11.6.18 — PogoDate stack-safe startup

## Before

STEP11.6.17 launched Tochi II Senshi, but selecting Hillslide rebooted the
device with FreeRTOS reporting a stack overflow in `pogopo_os`. The failure
happened before the PogoDate API banner, so it was not a missing Lua API. The
startup sound preloader recursively traversed the package tree while retaining
large path buffers in every 8 KiB task-stack frame.

## Changes

The short-sound scan is now an iterative, bounded breadth-first traversal. Its
64-directory queue and all large path/stat scratch storage live in PSRAM and are
released before Lua starts. The UI/runtime task stack is increased from 8 KiB
to 12 KiB for nested CoreLib import chains. PDX startup now logs the task's
minimum free stack before and after loading, while the sound scan reports its
directory count, skipped entries and cached bytes.

## Result

A synthetic package with seven nested sound directories starts, caches 61,020
bytes and runs without errors. The rebuilt suite also passes the STEP11.6.17
game-compatibility test, input, crank, synth, Maze 900-frame and Duel 1,800-frame
regressions. WOOD's eight progression captures remain byte-identical.

The actual Hillslide package is only present on the user's SD card, so the final
proof is the hardware run. If startup now reaches the `PogoDate API` banner and
then stops, the stack bug is fixed and the next complete Lua error identifies a
separate compatibility API to implement.

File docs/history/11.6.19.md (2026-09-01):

# STEP11.6.19 — PogoDate font-family compatibility

## Before

STEP11.6.18 removed Hillslide's native task-stack overflow. The game then
loaded all 35 Lua modules and reached `App.lua`, where startup stopped at line
23 because `playdate.graphics.font.newFamily` was missing. The reported
`pogopo_os` minimum of 2,872 B confirms this is a normal compatibility gap,
not a recurrence of the stack failure.

## Changes

`graphics.font.newFamily()` now builds SDK-style families keyed by
`normal`, `bold` and `italic`, loading each package PFT through the existing
compiled-font decoder. `graphics.setFontFamily()` and `getTextSize()` accept
the resulting family directly.

The neighboring text surface was completed at the same time: font-object
tracking and leading, global font tracking, font-object text drawing and
alignment, glyph image extraction, `getTextSizeForMaxWidth()`, wrap and
alignment constants, and the documented width/height/truncation results from
`drawTextInRect()`. PFT tracking is applied exactly once; global tracking is
then added independently.

## Result

A host probe starts the real 53-module Maze PDX, creates a three-face family
from three real PFT resources, switches it into the graphics context, measures
and draws text, changes tracking and leading, extracts a glyph image and tests
bounded text sizing. It passes with no Lua errors.

The rebuilt regressions also pass input responders, crank and synth probes,
the seven-level stack-safe SFX package, Maze for 900 frames, Duel Of Shadows
for 1,800 frames and the STEP11.6.17 graphics/sprite/pathfinder suite. WOOD's
eight progression captures are byte-identical to STEP11.6.18.

Hillslide itself remains an on-device test because its package is not included
in this source archive. Its next run should pass `App.lua:23`; any later full
Lua error is the next package-independent API target.

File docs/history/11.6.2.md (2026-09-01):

# STEP11.6.2 — Noble focus, aligned PFT text and correct stereo PDA

## Before

STEP11.6.1 added Noble system-font APIs, but Maze still stopped on missing focus rendering while Duel Of Shadows exposed PFT alignment and stereo PDA decoding defects.

## Changes

`lockFocus()` and `unlockFocus()` were added, PFT glyph offsets were aligned against the complete font stream, stereo IMA ADPCM nibble decoding was corrected, and slow Lua frames now yield safely to avoid starving the watchdog. :contentReference[oaicite:0]{index=0}

## Result

Maze can progress past the Noble focus API, Duel Of Shadows regains its missing text and clean audio, and over-budget Lua frames no longer trigger IDLE0 watchdog starvation.

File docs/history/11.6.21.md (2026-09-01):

# STEP11.6.21 — PogoDate menu key repeat and system glyph fallback

## Before

STEP11.6.20 let Hillslide finish all 35 Lua modules and report `PogoDate Lite
ready`. Its main menu appeared, proving that font families and callable scene
classes were working. Pressing right or down then stopped input dispatch at
`scenes/MainMenu.lua:143` because `playdate.timer.keyRepeatTimer` was nil.
Characters used as menu decorations also appeared as `?` on both sides of
each label.

## Cause

PogoDate implemented ordinary millisecond timers and frame timers but omitted
the SDK's two key-repeat constructors. Hillslide uses that standard helper to
move once on the initial D-pad press and continue moving while the direction
is held.

The PFT renderer handled missing custom-font characters by substituting the
custom font's question-mark glyph. Playdate instead falls back to its system
font when possible. Nontendo-style fonts commonly omit arrows and menu
brackets, which exposed the difference.

## Changes

- added `playdate.timer.keyRepeatTimer(callback, ...)` with the SDK defaults:
  immediate callback, 300 ms initial delay and 100 ms repeats;
- added `keyRepeatTimerWithDelay(initialDelay, repeatDelay, callback, ...)`;
- preserved the SDK callback rule: explicit arguments are forwarded, while a
  callback without arguments receives the timer object;
- returned ordinary removable/pausable timer tables and switched from the
  initial delay to the repeat delay after the first timed firing;
- added system-font fallback for ASCII characters missing from compiled PFTs;
- mapped common Unicode left/right/up/down arrows and triangle symbols to
  compact system direction glyphs;
- kept text measurement and glyph-image extraction consistent with rendering.

## Result

A dedicated host regression checks immediate, initial-delay and repeat-delay
firings, callback arguments, the timer-object callback form and removal. It
also loads a real PFT which lacks `<`, compares its fallback glyph pixel by
pixel with the system font, and verifies Unicode directional widths.

The rebuilt suite passes the STEP11.6.20 callable-scene regression, the real
three-PFT family test, sprite/tilemap/image/pathfinder coverage, input
responders, crank, synth, deep-SFX startup, Maze for 900 frames, Duel Of
Shadows for 1,800 frames, Celeste for 300 frames, Godspeed through game over
and Frogger startup. WOOD's eight progression captures are byte-identical to
STEP11.6.20.

The next hardware proof is Hillslide menu navigation: each D-pad press should
move the selection without an input error, holding a direction should repeat,
and the decoration characters should no longer be question marks.

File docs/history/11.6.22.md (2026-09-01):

# STEP11.6.22 — Hillslide complete API pass

## Before

STEP11.6.21 let Hillslide reach its main menu, navigate with key repeat and
render the circled A/B decorations. Repeated menu movement then stopped in
`Audio.lua:153` because sample players had no `getOffset()` method. Testing one
missing call at a time would leave several later scene and gameplay paths
uncovered.

## Cause

PogoDate's sample/file player stored only a boolean playing state, volume and
rate. It did not expose playback position or volume getters, and a completed
one-shot sample remained marked as playing forever. Hillslide uses those three
behaviours to select a reusable SFX voice. Its later game scene also uses the
SDK spelling `clearStencilImage()` and submits the final score asynchronously.

The game additionally authors the resource path `assets/art/avalanche` while
the compiled file is `Avalanche.pdt`. Playdate resource lookup accepts that
case difference, but a case-sensitive host filesystem did not.

## Changes

- inspected every one of Hillslide's 35 compiled Lua modules instead of only
  following the first runtime error;
- added sample/file-player `getOffset()`, `setOffset()` and `getVolume()`;
- made pause preserve position, stop reset it and non-looping `isPlaying()`
  become false after the real PDA duration;
- added stored loop-range state and preserved an explicit offset on the next
  `play()` call;
- added `graphics.clearStencilImage()` as the SDK alias for clearing the
  current stencil;
- added asynchronous offline-compatible `scoreboards.addScore()`,
  `getScores()`, `getPersonalBest()` and `getScoreboards()` callback shapes;
- added case-insensitive compiled image/image-table filename recovery without
  package-name or asset-specific substitutions;
- log a requested image-table path when no compiled resource can be found.

## Result

The real package passes a dedicated semantic probe for playback offsets,
volume, one-shot completion, looping file players, stencil clearing and the
scoreboard callback. Fresh-runtime probes then open main menu, score menu,
credits, handbook, tasks, upgrades, Training, the main game and Recap. The
main-game probe runs 1,000 logical frames; every scene finishes with zero Lua
errors.

Regressions pass for key repeat/system glyph fallback, callable scenes, real
font families, the 92-method game-compatibility harvest, deep SFX startup,
input responders, crank and synth. Maze runs 900 frames and Duel Of Shadows
runs its 1,800-frame boss path with zero Lua errors. WOOD reaches its playable
room at 20 FPS and keeps all eight progression checksums.

All Playdate API calls statically referenced by Hillslide's supplied Lua
modules now exist in PogoDate. This does not claim complete Playdate OS
emulation: scoreboard results are offline placeholders and actual audio loop
subranges are still approximated by the current decoded-audio backend.

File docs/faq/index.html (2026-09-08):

Skip to content

pogopodocumentation Search docs/ (https://github.com/lastlxrd/Pogopo)

A small, evolving reference for the pogopo hardware and pogopoOS firmware.

Project

# FAQ

The questions a developer, hardware engineer, or interviewer is most likely to ask when reviewing pogopo for the first time.

## What is pogopo?

pogopo is a compact handheld game console and modular pocket platform. It combines a custom ESP32-S3 board, a 400 × 240 Sharp Memory LCD, physical controls, audio, storage, motion sensing, and a purpose-built firmware called PogopoOS.

## Why ESP32-S3?

The project uses its two CPU cores, SPI/I²C/I²S/SDMMC peripherals, external-memory support, and ESP-IDF/FreeRTOS environment. Those capabilities are used directly by the display, controls, audio, storage, motion, and emulator task split.

## Why a monochrome Sharp Memory LCD?

The panel gives pogopo a crisp, readable 1-bit image and keeps static pixels visible without a continuous full-screen refresh. Unlike a typical e-paper display, it is fast enough for interactive UI and approximately 30 FPS Game Boy presentation.

## What is PogopoOS?

PogopoOS is custom ESP-IDF/C++ firmware. It initializes the board, exposes hardware services, renders the interface, runs applications, manages settings and power, and integrates the Game Boy runtime.

## Does it run Linux?

No. PogopoOS is an embedded firmware stack running directly on ESP-IDF and FreeRTOS. It does not boot a Linux kernel or use a desktop operating-system environment.

## Can it emulate Game Boy?

Yes. The working runtime uses Peanut-GB and MiniGB APU and reads .gb files from /gameboy. The documented baseline advances the Game Boy CPU at 59.7 Hz and presents to the Sharp LCD at approximately 29.9 Hz.

## How are apps and games made?

Native software implements the shared application interface and uses PogopoOS services instead of owning peripherals directly. Apps can draw through the graphics layer and receive input, audio, haptics, storage, motion, power, and settings dependencies from the app manager.

## What is the modular expansion system?

It is a planned mechanical and electrical attachment area on the right side of the console. The goal is to connect interchangeable hardware such as extra controls, sensors, wireless functions, storage, or experimental electronics. The final connector, power limits, protocol, and verified module list are still work in progress.

## Is pogopo open source?

Project-authored PogopoOS source code and documentation are available under Apache-2.0. Third-party components, games, fonts, and artwork keep their own licenses; see the license page and repository notices for the exact boundary.

## What did I design and build myself?

I designed the pogopo handheld platform around a custom PCB and enclosure concept and implemented the current PogopoOS firmware: board drivers, services, 1-bit UI, launcher, settings, power behavior, diagnostics, asset pipeline, and Game Boy integration/optimization. Third-party emulator cores are identified in the repository and remain under their own licenses.

## What is finished and what is still experimental?

Working parts include board bring-up, the Sharp display path, controls, audio, haptics, microSD, motion and power services, launcher/settings UI, startup/shutdown behavior, and Game Boy runtime. The modular connector specification, verified expansion modules, broader native game library, other runtimes, final portfolio photography, and several formal reliability benchmarks are still experimental or planned.

pogopo documentation ·

## On this page

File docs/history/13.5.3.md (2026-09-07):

# STEP13.5.3

- Doubled the OS task stack for deep PDZ loading and shutdown callbacks.
- Restored legacy string variants for `getSystemFont`.
- Recovered the full Game Boy fast-RAM arena after leaving PogoDate.
- Preserved the internal Playdate screen with the larger task stack.

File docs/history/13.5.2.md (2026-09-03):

# STEP13.5.2

- Increased the early contiguous SRAM reservation so the 96 KiB Playdate screen fits.
- Added an explicit internal-RAM versus PSRAM screen allocation diagnostic.

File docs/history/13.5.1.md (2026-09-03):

# STEP13.5.1

- Fixed strict compiler initialization-order validation in the PogoDate app.

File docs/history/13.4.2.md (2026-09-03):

# STEP13.4.2

- Expanded eight PDI/PDT pixels per blit operation for faster sprite drawing.
- Removed two unused-variable build warnings from lazy sound loading.
- Kept the PSRAM PDZ cache and detailed PogoDate profiler.

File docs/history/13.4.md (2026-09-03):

# STEP13.4 — Pogofont system typography

STEP13.4 makes the embedded Pogofont family the visual system font for the
Pogopo shell and the Playdate compatibility runtime.

## Changes

- The system Regular and Regular Italic faces are available through the
  Playdate font API.
- `playdate.graphics.getSystemFont(2)` selects the italic system face.
- A missing or unsupported `.pft` now falls back to Pogofont instead of the
  legacy 5x7 bitmap face.
- Fallback fonts read their requested pixel size from names such as
  `Roobert-11` and `Roobert-20`, then scale the nearest packed Pogofont face.
- Missing glyphs inside an otherwise valid game font use Pogofont at that
  font's own height.
- Valid game-provided PFT fonts are preserved so a game's intended art
  direction and layout are not replaced globally.
- Playdate and Game Boy launch/error panels, power messages, and common GUI
  header/footer chrome use Pogofont Regular or Regular Italic.

## Verification

- All six packed faces (Regular/Italic at 14, 22, and 24 px source sizes)
  validate against the embedded 745,556-byte asset blob.
- System Regular, system Italic, and a requested 20 px missing-font fallback
  render through the Playdate API with zero Lua errors.
- XTRIS effects regression: 820 frames, zero runtime errors and zero effect
  fallback events.
- Binairo Continue regression: 360 frames, zero errors and zero stops.
- Font, GUI, and Playdate runtime sources pass host compilation with warnings
  treated as errors.

## Hardware check

1. Open the Playdate browser and confirm its title, selected row, metadata,
   status, and footer match the Game Boy browser style.
2. Launch a game that uses the Playdate system font and verify Regular and
   Italic remain readable at the compact default size.
3. Launch games with 11 px and 20 px fallback font requests and confirm their
   original line spacing is retained.
4. Confirm XTRIS and other games with bundled PFT fonts keep their own font
   design while unsupported characters still render.

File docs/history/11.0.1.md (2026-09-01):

# STEP11.0.1 — PDSnake CMake fix

## Before

STEP11.0 could not build because the Playdate component used a non-scriptable CMake command during early component expansion.

## Changes

The source-file properties were moved after component registration and the build target was pinned to ESP32-S3.

## Result

After building and flashing, PDSnake launched successfully and worked correctly, confirming that the Lua compatibility runtime was functional.

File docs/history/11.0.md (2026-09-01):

# STEP11.0 — PogoDate / PDSnake source-Lua proof

## Before

STEP9.5.2 provided a stable Game Boy build, while the failed GBA experiment was removed.

## Changes

A small Playdate-compatible Lua runtime and the original PDSnake source modules were added.

## Result

The project did not build because `set_source_files_properties()` was called from a non-scriptable CMake requirements pass, so the firmware could not be flashed or tested.

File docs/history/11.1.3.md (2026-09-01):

# STEP11.1.3 — Celeste native fill and Sharp 2x fast path

## Before

Celeste ran at only about 13–14 FPS because Lua rendering and final framebuffer scaling were too expensive.

## Changes

Fullscreen 2x scaling, filled rectangles and common image blits were replaced with optimized native fast paths. :contentReference[oaicite:0]{index=0}

## Result

After building and flashing, Celeste reached approximately 29–31 Lua FPS and 28–30 LCD FPS with no Lua errors, although original Playdate sound assets were still unsupported.

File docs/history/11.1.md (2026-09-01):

# STEP11.1 — Celeste Classic compatibility test

## Before

PDSnake built and ran correctly, proving that the basic Playdate Lua runtime worked.

## Changes

Celeste Classic and the additional Playdate sprite, tilemap, collision, image and input APIs required by the game were added.

## Result

After building and flashing, Celeste launched but ran at only about 5 FPS, making the first port effectively unplayable.

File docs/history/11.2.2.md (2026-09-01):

# STEP11.2.2 — Playdate PDZ opcode compatibility fix

## Before

Valid Playdate PDZ packages were detected but became stuck during execution because their Lua opcode order differed from stock Lua 5.4.

## Changes

Playdate Lua 5.4-beta opcodes are now normalized to the stock Lua 5.4 layout before execution. :contentReference[oaicite:0]{index=0}

## Result

Celeste successfully loaded from SD and ran at approximately 29–31 Lua FPS and 26–30 LCD FPS, while Onebit Frogger reached Lua execution but stopped because the `playdate.file` API was not yet implemented.

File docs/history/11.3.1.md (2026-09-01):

# STEP11.3.1 — Playdate image rotation compatibility

## Before

Onebit Frogger loaded from SD but stopped because `playdate.graphics.image:drawRotated()` was missing.

## Changes

The Playdate-compatible `drawRotated()` image method was added with rotation, scaling, clipping, stencil and draw-mode support. :contentReference[oaicite:0]{index=0}

## Result

Frogger progressed past image rotation and started its update loop, but then stopped because `btnp()` accepted only numeric button IDs while the game passed a string.

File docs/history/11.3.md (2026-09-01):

# STEP11.3 — 50 FPS Celeste test and Playdate file API

## Before

Celeste ran from SD at about 30 FPS, while Onebit Frogger failed during startup because `playdate.file` was missing.

## Changes

Celeste was configured for a 50 FPS test and the Playdate file API was implemented with per-game sandboxed storage. :contentReference[oaicite:0]{index=0}

## Result

Onebit Frogger successfully loaded its PDZ and started from SD, but stopped on the first update because the image method `drawRotated` was not yet implemented.

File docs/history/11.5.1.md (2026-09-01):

# STEP11.5.1 — Correct Playdate colors and measurable partial LCD updates

## Before

STEP11.5 added real PFT fonts and broader PDX compatibility, but Onebit Frogger still rendered incorrect colors and Sharp partial-update behavior was not visible in runtime diagnostics.

## Changes

Playdate color values are now translated correctly into PogoDate's internal framebuffer format, the 400 x 240 presentation path was optimized, and performance logs now report dirty Sharp rows and transfer timing. :contentReference[oaicite:0]{index=0}

## Result

Onebit Frogger now uses the intended black and white palette while preserving its authored 20 FPS timing, and physical LCD update cost can now be measured directly from serial diagnostics.

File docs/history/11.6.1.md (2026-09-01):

# STEP11.6.1 — Noble system fonts and unambiguous firmware identification

## Before

STEP11.6 expanded Lua PDX compatibility, but a previously unseen Noble Engine package stopped on the missing Playdate system-font API and older flashed builds were difficult to distinguish from the current source.

## Changes

`playdate.graphics.getSystemFont()` and `getFont()` were added with persistent system-font handling, while explicit STEP11.6.1 identification lines were added to the hardware log. :contentReference[oaicite:0]{index=0}

## Result

Noble Engine packages can now access the expected system-font API, and serial output clearly confirms whether the correct STEP11.6.1 firmware is actually running.

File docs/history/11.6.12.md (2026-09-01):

# STEP11.6.12 — Complete Lua crank compatibility surface

## Before

STEP11.6.11 added Playdate synth support, but some Lua PDX packages still stopped during startup when they reached the missing crank API.

## Changes

The complete documented Lua crank surface was added, including position, change, ticks, dock state, crank callbacks, input-handler routing and the shared crank-indicator object, with a deterministic neutral state on Pogopo until physical crank hardware exists. :contentReference[oaicite:0]{index=0}

## Result

Packages that inspect or initialize Playdate crank functionality can now continue past startup, while crank API probes, UBSan and the existing Maze, Duel, Celeste, Godspeed and Frogger regressions remain stable.

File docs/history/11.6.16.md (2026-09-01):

# STEP11.6.16 — Playdate API harvest 1

## Before

STEP11.6.15 made Pulp controls playable, but broad compatibility was still
blocked by missing leaf APIs commonly used by bundled CoreLibs and independent
Lua games: most geometry types, JSON encoding, several graphics primitives,
display-state getters and useful system-menu item objects.

## Changes

PogoDate now implements rect, point, size, vector, line-segment, polygon, arc
and affine-transform operations; compact/pretty/file JSON encoding; triangle,
polygon and ellipse drawing; renderer-backed display/graphics getters; and
mutable menu items with values and callbacks. These are generic runtime APIs,
with no new package-name workaround.

## Result

The new API-harvest regression passes alongside input, crank, synth, Maze,
Duel and WOOD tests. WOOD still reaches its playable room at its authored
20 FPS and produces the same progression frame checksums as STEP11.6.15.

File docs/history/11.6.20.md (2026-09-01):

# STEP11.6.20 — PogoDate CoreLibs object and scene classes

## Before

STEP11.6.19 removed Hillslide's `font.newFamily` failure and loaded its three
real PFT faces. Startup then stopped at `App.lua:88` with `attempt to call a
table value (local 'scene')`. The task retained 2,952 B of native stack, so
this was another Lua compatibility issue rather than stack exhaustion.

## Cause

PogoDate's original compact `class()` helper created callable classes but did
not reproduce the complete `CoreLibs/object.lua` instance layout. On Playdate,
each instance stores its concrete callable class in `instance.super`. PogoDate
instead exposed the parent table through lookup. A scene manager which saved
that value and later executed `scene()` therefore attempted to call an ordinary
table.

## Changes

The object layer now follows the official SDK 3.0.5 behavior for:

- concrete `instance.super` class links and callable scene reconstruction;
- `class`, `className`, `baseObject`, `init` and `isa` relationships;
- class property tables and optional namespace registration;
- inherited Lua metamethods used for operators and object presentation;
- subclass allocation through the parent's `baseObject()`;
- the SDK's nil return from `class(...).extends(...)`;
- `Object:tableDump()` and `printTable()` debugging helpers.

Sprite subclasses expose the same class metadata and allocation hook without
changing PogoDate's existing sprite storage. The font-family constants are now
the SDK's numeric normal/bold/italic variants, while string-keyed families
remain accepted. `graphics.getTextSizeForMaxWidth()` also uses the documented
argument order: text, maximum width, leading adjustment, then font.

## Result

A dedicated regression recreates Hillslide's failing scene pattern: construct
a namespaced scene instance, save its `instance.super` table, then call that
table to construct the next scene. It also covers property-backed classes,
custom `baseObject`, inheritance, `isa`, copied metamethods and sprite
subclasses.

The rebuilt suite additionally passes the real three-PFT family probe,
Godspeed through game over, Frogger startup, Celeste 300 logical frames, Maze
900 frames, Duel Of Shadows 1,800 frames, input responders, crank, synth and
deep-SFX probes. WOOD's eight progression captures are byte-identical to
STEP11.6.19.

The user's Hillslide PDX remains the final hardware proof. STEP11.6.20 should
pass `App.lua:88`; the next complete Lua error, if any, identifies the next
package-independent API gap.

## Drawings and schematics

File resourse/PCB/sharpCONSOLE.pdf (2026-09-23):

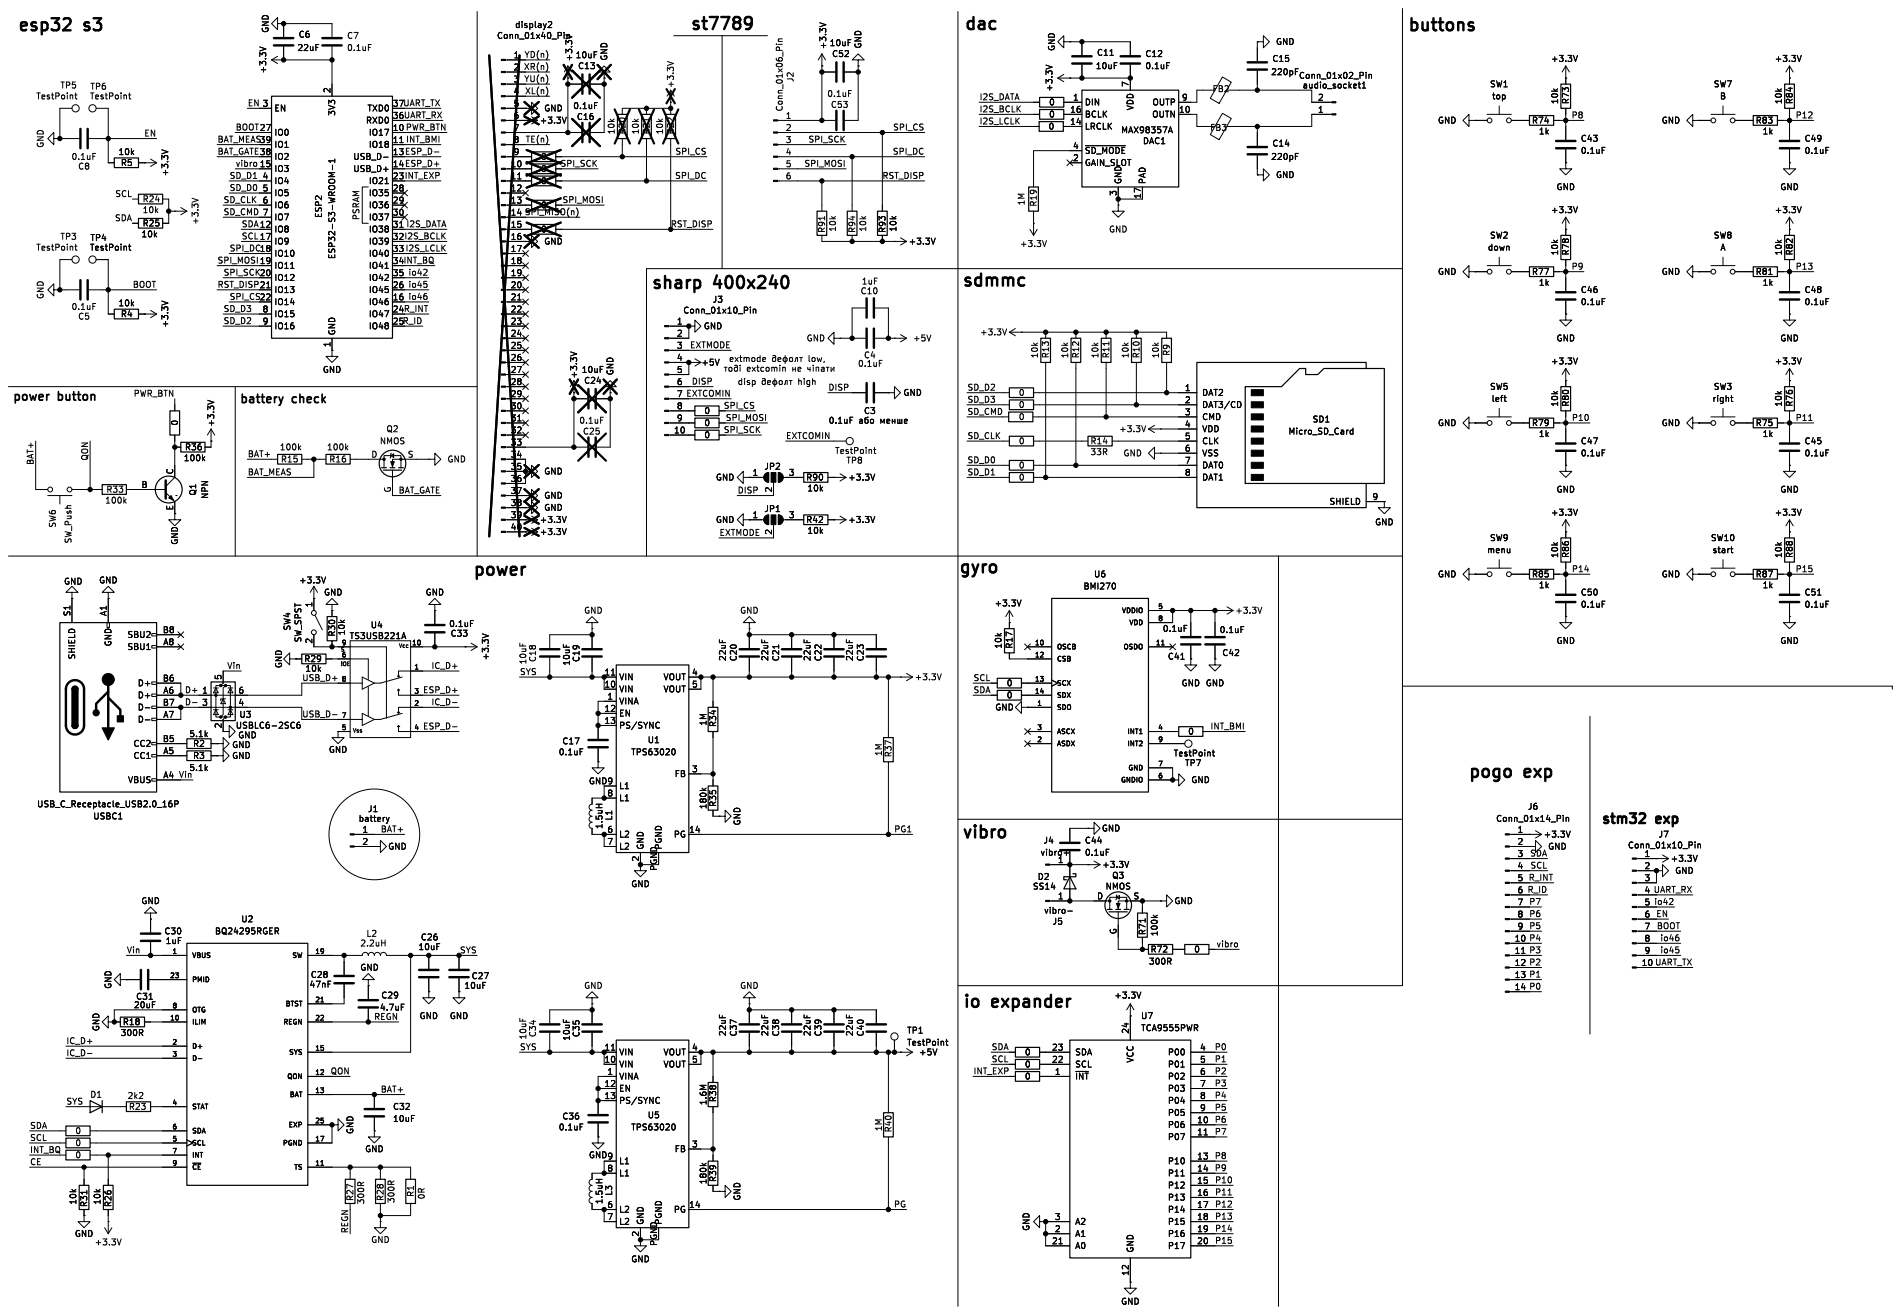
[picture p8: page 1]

0.1uF GND
VOUT 4 VOUT 5 FB 3 PG 14 GND GND

VIN 11 VIN 10 VINA 1 EN 12 PS/SYNC 13

U1 TPS63020 VIN 11 VIN 10 VINA 1 EN 12 PS/SYNC 13

GND
VOUT 4 VOUT 5 FB 3 PG 14

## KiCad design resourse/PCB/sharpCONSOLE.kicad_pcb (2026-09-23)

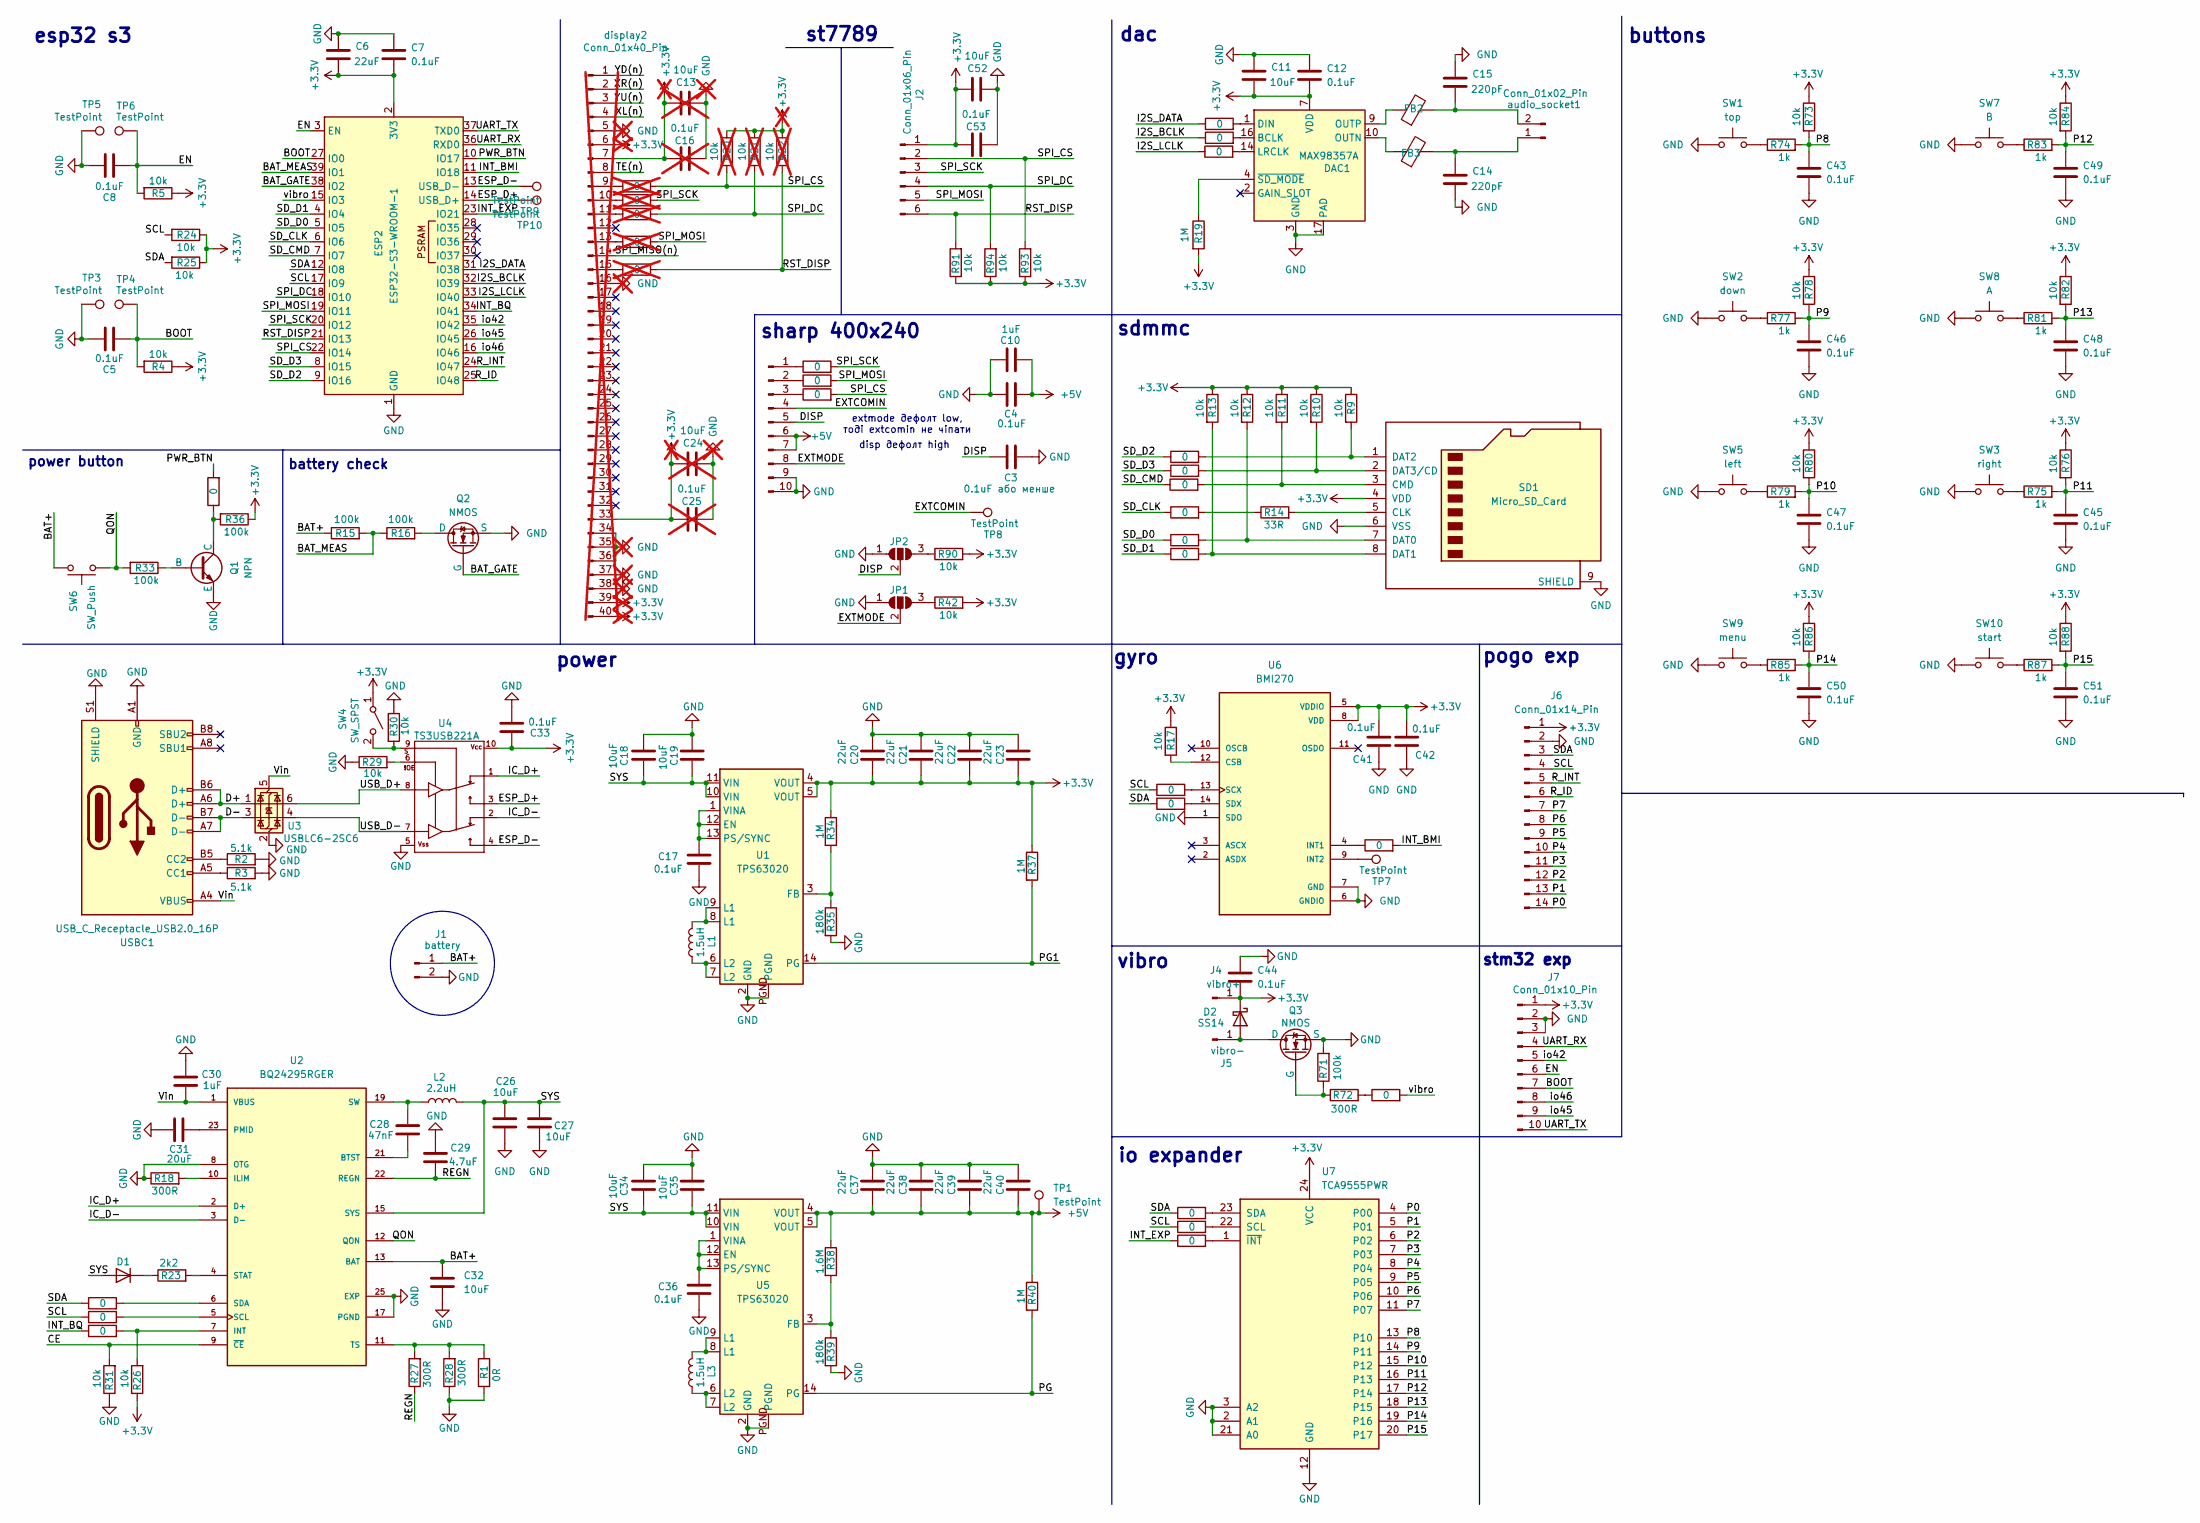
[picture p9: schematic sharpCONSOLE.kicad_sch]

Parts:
C3: 0.1uF або менше; C_0805_2012Metric
C4, C5, C7, C8, C12, C17, C33, C36, C41, C42, C43, C44, C45, C46, C47, C48, C49, C50, C51, C53: 0.1uF; C_0805_2012Metric
C6, C20, C21, C22, C23, C37, C38, C39, C40: 22uF; C_0805_2012Metric
C10, C30: 1uF; C_0805_2012Metric
C11, C18, C19, C26, C27, C32, C34, C35, C52: 10uF; C_0805_2012Metric
C13, C24: 10uF; C_0805_2012Metric; not fitted
C14, C15: 220pF; C_0805_2012Metric
C16, C25: 0.1uF; C_0805_2012Metric; not fitted
C28: 47nF; C_0805_2012Metric
C29: 4.7uF; C_0805_2012Metric
C31: 20uF; C_0805_2012Metric
D1: D; LED_0805_2012Metric
D2: SS14; D_SMA
DAC1: MAX98357A; TQFN-16-1EP_3x3mm_P0.5mm_EP1.23x1.23mm
ESP2: ESP32-S3-WROOM-1
FB2, FB3: 600; R_0805_2012Metric
J1: battery; PinHeader_1x02_P2.54mm_Vertical
J2: Conn_01x06_Pin; pad_6pin
J4: vibro+; TestPoint_Pad_1.5x1.5mm
J5: vibro-; TestPoint_Pad_1.5x1.5mm
J6: Conn_01x14_Pin; pads rp2040
J7: Conn_01x10_Pin; pad_10pin
J9: Conn_01x10_Pin; TE_1-1734839-0_1x10-1MP_P0.5mm_Horizontal
JP1, JP2: SolderJumper_3_Open; SolderJumper-3_P1.3mm_Open_RoundedPad1.0x1.5mm
L1, L3: 1.5uH; L_Chilisin_BMRA00050530
L2: 2.2uH; L_Chilisin_BMRA00050530
Q1: NPN; SOT-23-3
Q2, Q3: NMOS; SOT-23
R1: 0R; R_0805_2012Metric
R2, R3: 5.1k; R_0805_2012Metric
R4, R5, R9, R10, R11, R12, R13, R17, R24, R25, R26, R29, R30, R31, R42, R73, R76, R78, R80, R82, R84, R86, R88, R90, R91, R93, R94: 10k; R_0805_2012Metric
R14: 33R; R_0805_2012Metric
R15, R16, R33, R36, R71: 100k; R_0805_2012Metric
R18, R27, R28, R72: 300R; R_0805_2012Metric
R19, R34, R37, R40: 1M; R_0805_2012Metric
R20, R21, R22: 10k; R_0805_2012Metric; not fitted
R23: 2k2; R_0805_2012Metric
R35, R39: 180k; R_0805_2012Metric
R38: 1.6M; R_0805_2012Metric
R43, R44, R45, R46, R47, R48, R52, R53, R54, R55, R56, R57, R58, R59, R60, R61, R62, R63, R64, R70, R96, R97, R98: 0; R_0402_1005Metric
R65, R66, R67, R68, R69: 0; R_0402_1005Metric; not fitted
R74, R75, R77, R79, R81, R83, R85, R87: 1k; R_0805_2012Metric
SD1: Micro_SD_Card; microSD_HC_Hirose_DM3AT-SF-PEJM5
SW1: top; SW_Dome_10mm
SW2: down; SW_Dome_10mm
SW3: right; SW_Dome_10mm
SW4: SW_SPST; SW_DIP_SPSTx01_Slide_Copal_CVS-01xB_W5.9mm_P1mm
SW5: left; SW_Dome_10mm
SW6: SW_Push; SW_SPST_B3U-3000P
SW7: B; SW_Dome_10mm
SW8: A; SW_Dome_10mm
SW9: menu; SW_Dome_10mm
SW10: start; SW_Dome_10mm
TP1: TestPoint; TestPoint_Pad_1.5x1.5mm
TP3, TP4, TP5, TP6, TP9, TP10: TestPoint; TestPoint_Pad_D1.0mm
TP7, TP8: TestPoint; TestPoint_Pad_1.0x1.0mm
U1, U5: TPS63020
U2: BQ24295RGER; IC_BQ24295RGER; PARTREV B
U3: USBLC6-2SC6; SOT-23-6
U4: TS3USB221A; QFN-10-RSE
U6: BMI270; XDCR_BMI270
U7: TCA9555PWR; TSSOP-24_4.4x7.8mm_P0.65mm
USBC1: USB_C_Receptacle_USB2.0_16P; USB_C_Receptacle_GCT_USB4110
audio_socket1: Conn_01x02_Pin; PinHeader_1x02_P2.00mm_Vertical
display2: Conn_01x40_Pin; Hirose_FH12-40S-0.5SH_1x40-1MP_P0.50mm_Horizontal; not fitted

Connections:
+3.3V: C6.2, C7.2, C11.2, C12.2, C13.2, C16.2, C20.1, C21.1, C22.1, C23.1, C24.2, C25.2, C33.2, C41.2, C42.2, C44.2, C52.2, C53.2, D2.1 (K), DAC1.7 (VDD), DAC1.8 (VDD), ESP2.2 (3V3), J2.1, J4.1, J6.1, J7.1, R4.1, R5.1, R9.1, R10.1, R11.1, R12.1, R13.1, R17.1, R19.2, R20.1, R21.1, R22.1, R24.1, R25.1, R26.1, R34.1, R36.1, R37.1, R42.2, R73.1, R76.1, R78.1, R80.1, R82.1, R84.1, R86.1, R88.1, R90.2, R91.1, R93.1, R94.1, SD1.4 (VDD), SW4.1 (A), U1.4 (VOUT), U1.5 (VOUT), U4.10, U6.5 (VDDIO), U6.8 (VDD), U7.24 (VCC), display2.6, display2.7, display2.33, display2.39, display2.40
+5V: C4.2, C10.2, C37.1, C38.1, C39.1, C40.1, J9.6, J9.7, R38.1, R40.1, TP1.1, U5.4 (VOUT), U5.5 (VOUT)
/BAT+: C32.1, J1.1, R15.1, SW6.2, U2.13 (BAT), U2.14 (BAT)
/BAT_GATE: ESP2.38 (IO2), Q2.2 (G)
/BAT_MEAS: ESP2.39 (IO1), R15.2, R16.1
/BOOT: C5.1, ESP2.27 (IO0), J7.7, R4.2, TP4.1
/CE: R31.2, U2.9 (~CE)
/D+: U3.1 (I/O1), USBC1.A6 (D+), USBC1.B6 (D+)
/D-: U3.3 (I/O2), USBC1.A7 (D-), USBC1.B7 (D-)
/DISP: C3.1, J9.5, JP2.2 (C)
/EN: C8.1, ESP2.3 (EN), J7.6, R5.2, TP6.1
/ESP_D+: ESP2.14 (USB_D+), TP10.1, U4.3
/ESP_D-: ESP2.13 (USB_D-), TP9.1, U4.4
/EXTCOMIN: J9.4, TP8.1
/EXTMODE: J9.8, JP1.2 (C)
/I2S_BCLK: ESP2.32 (IO39), R62.1
/I2S_DATA: ESP2.31 (IO38), R61.1
/I2S_LCLK: ESP2.33 (IO40), R63.1
/IC_D+: U2.2 (D+), U4.1
/IC_D-: U2.3 (D-), U4.2
/INT_BMI: ESP2.11 (IO18), R55.2
/INT_BQ: ESP2.34 (IO41), R60.1
/INT_EXP: ESP2.23 (IO21), R54.1
/P0: J6.14, U7.4 (P00)
/P1: J6.13, U7.5 (P01)
/P2: J6.12, U7.6 (P02)
/P3: J6.11, U7.7 (P03)
/P4: J6.10, U7.8 (P04)
/P5: J6.9, U7.9 (P05)
/P6: J6.8, U7.10 (P06)
/P7: J6.7, U7.11 (P07)
/P8: C43.1, R73.2, R74.2, U7.13 (P10)
/P9: C46.1, R77.2, R78.2, U7.14 (P11)
/P10: C47.1, R79.2, R80.2, U7.15 (P12)
/P11: C45.1, R75.2, R76.2, U7.16 (P13)
/P12: C49.1, R83.2, R84.2, U7.17 (P14)
/P13: C48.1, R81.2, R82.2, U7.18 (P15)
/P14: C50.1, R85.2, R86.2, U7.19 (P16)
/P15: C51.1, R87.2, R88.2, U7.20 (P17)
/PG: R40.2, U5.14 (PG)
/PG1: R37.2, U1.14 (PG)
/PWR_BTN: ESP2.10 (IO17), R64.2
/QON: R33.2, SW6.1, U2.12 (QON)
/REGN: C29.1, R27.1, U2.22 (REGN)
/RST_DISP: ESP2.21 (IO13), J2.6, R22.2, R69.2, R91.2
/R_ID: ESP2.25 (IO48), J6.6
/R_INT: ESP2.24 (IO47), J6.5
/SCL: ESP2.17 (IO9), J6.4, R24.2, R53.1, R56.1, R59.1
/SDA: ESP2.12 (IO8), J6.3, R25.2, R52.1, R57.1, R58.1
/SD_CLK: ESP2.6 (IO6), R46.1
/SD_CMD: ESP2.7 (IO7), R45.1
/SD_D0: ESP2.5 (IO5), R47.1
/SD_D1: ESP2.4 (IO4), R48.1
/SD_D2: ESP2.9 (IO16), R43.1
/SD_D3: ESP2.8 (IO15), R44.1
/SPI_CS: ESP2.22 (IO14), J2.2, R20.2, R68.2, R93.2, R98.2
/SPI_DC: ESP2.18 (IO10), J2.4, R21.2, R66.2, R94.2
/SPI_MOSI: ESP2.19 (IO11), J2.5, R67.2, R97.2
/SPI_SCK: ESP2.20 (IO12), J2.3, R65.2, R96.2
/SYS: C18.2, C19.2, C26.1, C27.1, C34.2, C35.2, D1.2 (A), L2.2, U1.10 (VIN), U1.11 (VIN), U2.15 (SYS), U2.16 (SYS), U5.10 (VIN), U5.11 (VIN)
/UART_RX: ESP2.36 (RXD0), J7.4
/UART_TX: ESP2.37 (TXD0), J7.10
/USB_D+: U3.6 (I/O1), U4.8
/USB_D-: U3.4 (I/O2), U4.7
/io42: ESP2.35 (IO42), J7.5
/io45: ESP2.26 (IO45), J7.9
/io46: ESP2.16 (IO46), J7.8
/vibro: ESP2.15 (IO3), R70.2
GND: C3.2, C4.1, C5.2, C6.1, C7.1, C8.2, C10.1, C11.1, C12.1, C13.1, C14.2, C15.1, C16.1, C17.2, C18.1, C19.1, C20.2, C21.2, C22.2, C23.2, C24.1, C25.1, C26.2, C27.2, C29.2, C30.1, C31.1, C32.2, C33.1, C34.1, C35.1, C36.2, C37.2, C38.2, C39.2, C40.2, C41.1, C42.1, C43.2, C44.1, C45.2, C46.2, C47.2, C48.2, C49.2, C50.2, C51.2, C52.1, C53.1, DAC1.3 (GND), DAC1.11 (GND), DAC1.15 (GND), DAC1.17 (PAD), ESP2.1 (GND), ESP2.40 (GND), ESP2.41 (GND), J1.2, J6.2, J7.2, J7.3, J9.9, J9.10, JP1.1 (A), JP2.1 (A), Q1.3 (E), Q2.3 (S), Q3.3 (S), R1.2, R2.2, R3.2, R18.1, R28.1, R29.1, R30.1, R31.1, R35.2, R39.2, R71.2, SD1.6 (VSS), SD1.9 (SHIELD), SW1.1, SW2.1, SW3.1, SW5.1, SW7.1, SW8.1, SW9.1, SW10.1, TP3.1, TP5.1, U1.2 (GND), U1.PGND, U2.8 (OTG), U2.17 (PGND), U2.18 (PGND), U2.25 (EXP), U3.2 (GND), U4.5, U5.2 (GND), U5.PGND, U6.1 (SDO), U6.6 (GNDIO), U6.7 (GND), U7.2 (A1), U7.3 (A2), U7.12 (GND), U7.21 (A0), USBC1.A1 (GND), USBC1.A12 (GND), USBC1.B1 (GND), USBC1.B12 (GND), USBC1.S1 (SHIELD), display2.5, display2.16, display2.34, display2.35, display2.36, display2.37, display2.38
unnamed: C28.2, L2.1, U2.19 (SW), U2.20 (SW)
unnamed: D1.1 (K), R23.1
unnamed: D2.2 (A), J5.1, Q3.1 (D)
unnamed: DAC1.16 (BCLK), R62.2
unnamed: DAC1.1 (DIN), R61.2
unnamed: DAC1.14 (LRCLK), R63.2
unnamed: DAC1.10 (OUTN), FB3.1
unnamed: DAC1.9 (OUTP), FB2.1
unnamed: DAC1.4 (~SD_MODE), R19.1
unnamed: J9.1, R96.1
unnamed: J9.2, R97.1
unnamed: J9.3, R98.1
unnamed: JP1.3 (B), R42.1
unnamed: JP2.3 (B), R90.1
unnamed: L1.1, U1.6 (L2), U1.7 (L2)
unnamed: L1.2, U1.8 (L1), U1.9 (L1)
unnamed: L3.1, U5.6 (L2), U5.7 (L2)
unnamed: L3.2, U5.8 (L1), U5.9 (L1)
unnamed: Q1.2 (B), R33.1
unnamed: Q1.1 (C), R36.2, R64.1
unnamed: Q2.1 (D), R16.2
unnamed: Q3.2 (G), R71.1, R72.1
unnamed: R14.1, R46.2
unnamed: R29.2, U4.6
unnamed: R65.1, display2.10
unnamed: R66.1, display2.11
unnamed: R67.1, display2.13
unnamed: R68.1, display2.9
unnamed: R69.1, display2.15
unnamed: R70.1, R72.2
unnamed: R74.1, SW1.2
unnamed: R75.1, SW3.2
unnamed: R77.1, SW2.2
unnamed: R79.1, SW5.2
unnamed: R81.1, SW8.2
unnamed: R83.1, SW7.2
unnamed: R85.1, SW9.2
unnamed: R87.1, SW10.2
unnamed: R14.2, SD1.5 (CLK)
unnamed: R11.2, R45.2, SD1.3 (CMD)
unnamed: R12.2, R47.2, SD1.7 (DAT0)
unnamed: R13.2, R48.2, SD1.8 (DAT1)
unnamed: R9.2, R43.2, SD1.1 (DAT2)
unnamed: R10.2, R44.2, SD1.2 (DAT3/CD)
unnamed: R30.2, SW4.2 (B), U4.9
unnamed: C17.1, U1.1 (VINA), U1.12 (EN), U1.13 (PS/SYNC)
unnamed: R34.2, R35.1, U1.3 (FB)
unnamed: C28.1, U2.21 (BTST)
unnamed: R18.2, U2.10 (ILIM)
unnamed: R26.2, R60.2, U2.7 (INT)
unnamed: C31.2, U2.23 (PMID)
unnamed: R59.2, U2.5 (SCL)
unnamed: R58.2, U2.6 (SDA)
unnamed: R23.2, U2.4 (STAT)
unnamed: R1.1, R27.2, R28.2, U2.11 (TS)
unnamed: C36.1, U5.1 (VINA), U5.12 (EN), U5.13 (PS/SYNC)
unnamed: R38.2, R39.1, U5.3 (FB)
unnamed: R17.2, U6.12 (CSB)
unnamed: R55.1, U6.4 (INT1)
unnamed: TP7.1, U6.9 (INT2)
unnamed: R56.2, U6.13 (SCX)
unnamed: R57.2, U6.14 (SDX)
unnamed: R53.2, U7.22 (SCL)
unnamed: R52.2, U7.23 (SDA)
unnamed: R54.2, U7.1 (~INT)
unnamed: R3.1, USBC1.A5 (CC1)
unnamed: R2.1, USBC1.B5 (CC2)
unnamed: C14.1, FB3.2, audio_socket1.1
unnamed: C15.2, FB2.2, audio_socket1.2
VBUS: C30.2, U2.1 (VBUS), U2.24 (VBUS), U3.5 (VBUS), USBC1.A4 (VBUS), USBC1.A9 (VBUS), USBC1.B4 (VBUS), USBC1.B9 (VBUS)

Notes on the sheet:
stm32 exp
esp32 s3
power button
sdmmc
dac
power
buttons
io expander
st7789
gyro
disp дефолт high
pogo exp
battery check
sharp 400x240
vibro
extmode дефолт low, тоді extcomin не чіпати

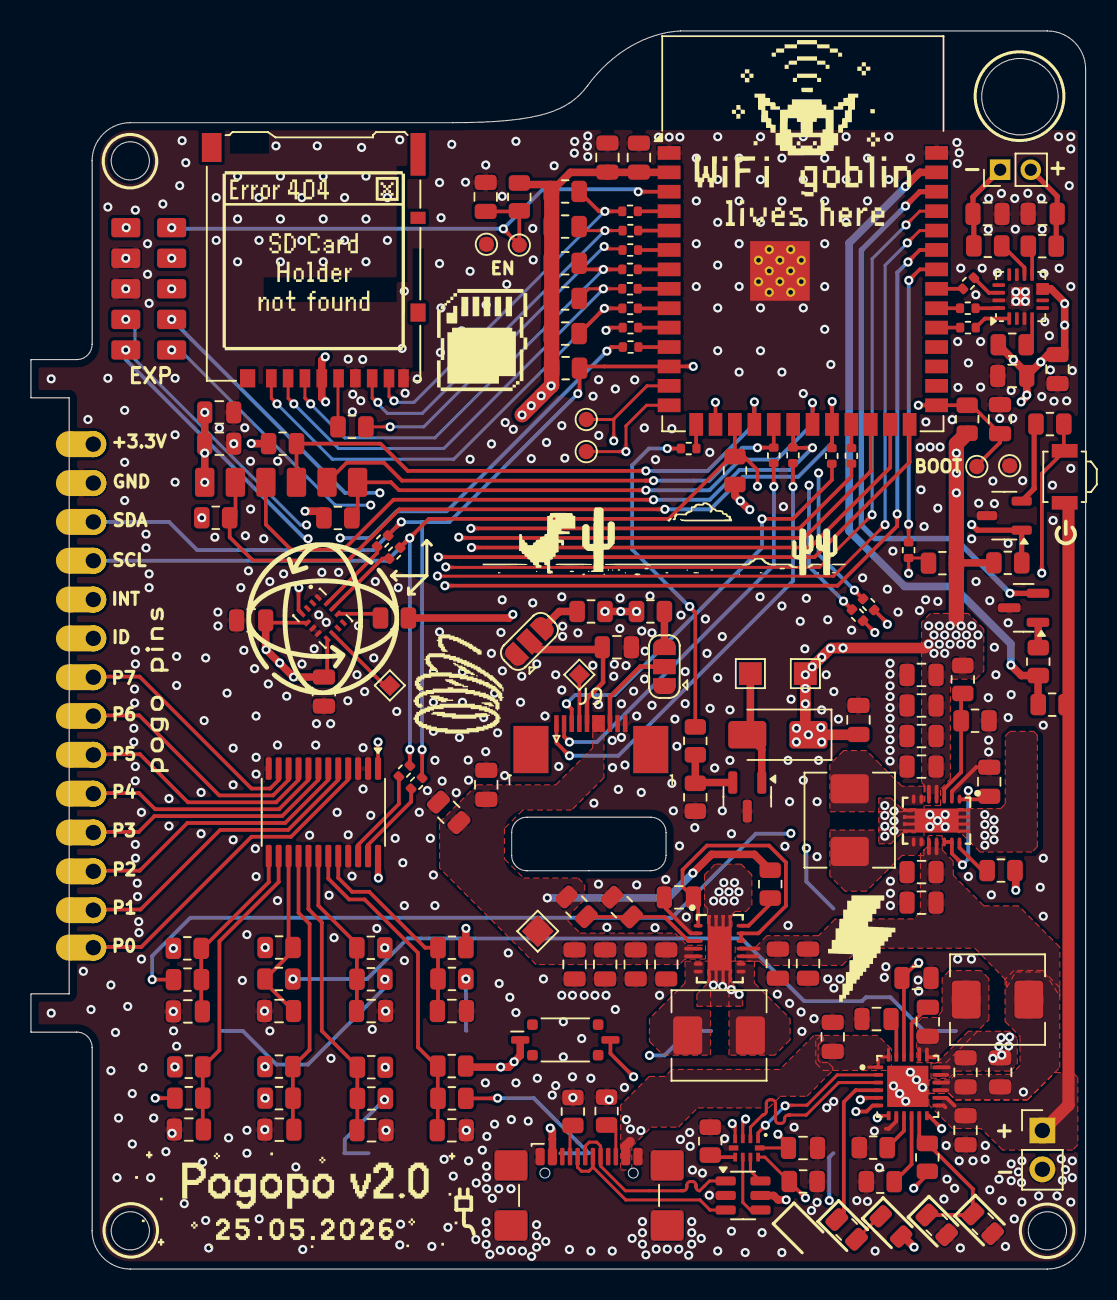
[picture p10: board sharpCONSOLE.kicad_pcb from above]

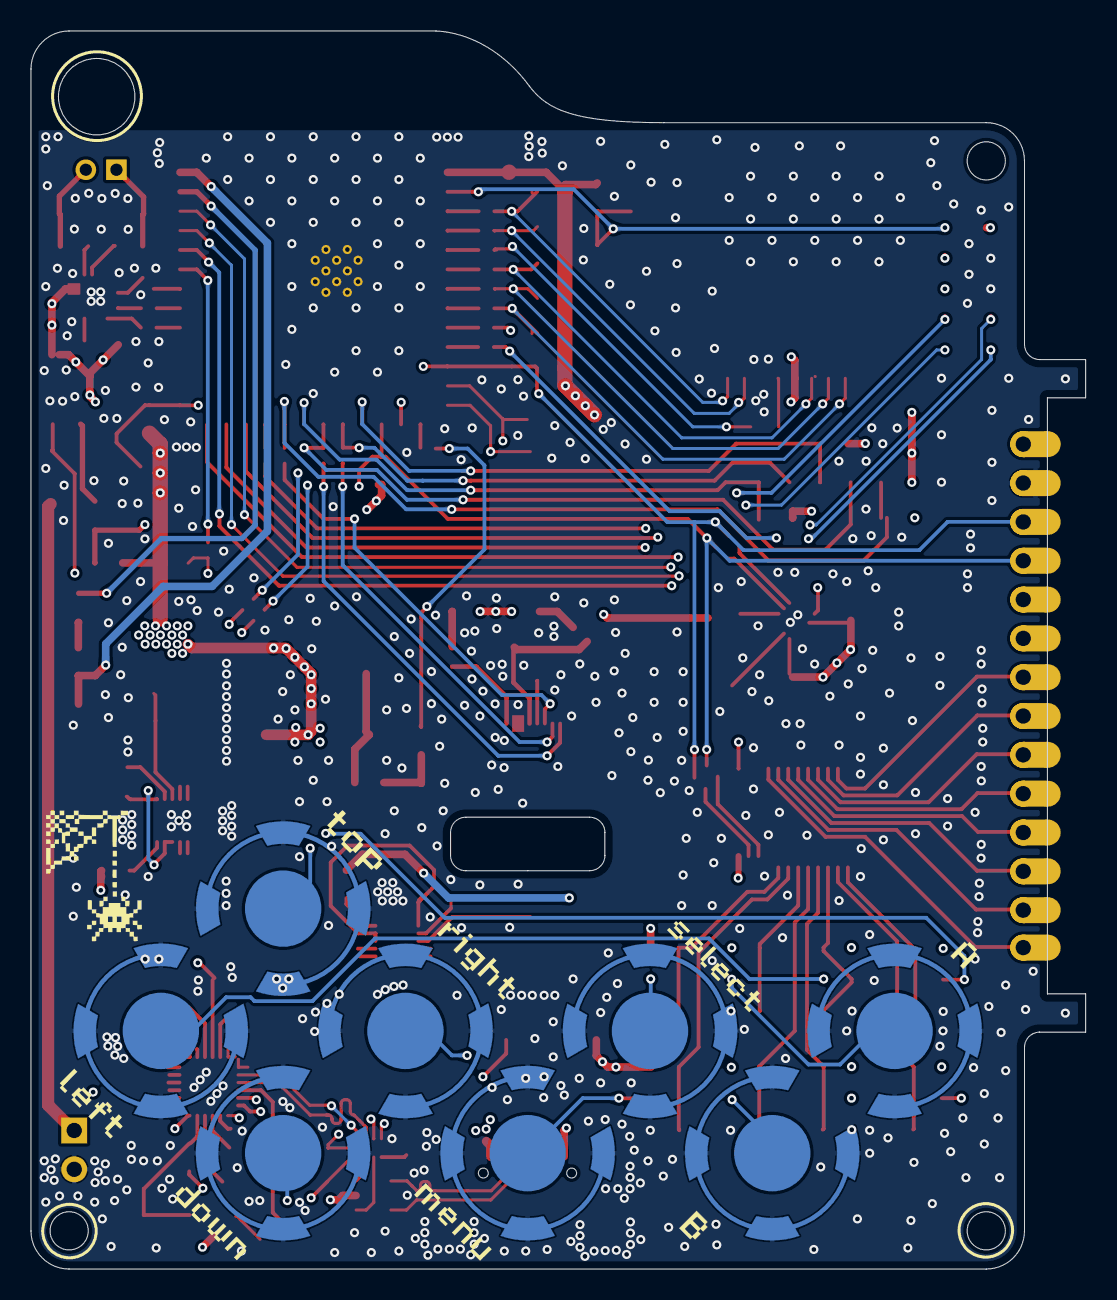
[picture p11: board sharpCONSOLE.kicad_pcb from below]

Board: 4 copper layers, 69.0 x 81.0 mm, 175 parts (8 on the bottom side), 134 nets.

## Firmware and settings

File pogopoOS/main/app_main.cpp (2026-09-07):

#include "i2c_bus.h"
#include "peripheral_tests.h"
#include "tasks.h"
#include "board_pins.h"
#include "system_state.h"
#include "apps/demo_apps.h"
#include "apps/gameboy_apps.h"
#include "apps/playdate_apps.h"

#include "pogopo_app.h"
#include "pogopo_gui.h"
#include "pogopo/gfx/gfx.h"
#include "pogopo_input.h"
#include "pogopo_haptics.h"
#include "pogopo_audio.h"
#include "pogopo_storage.h"
#include "pogopo_imu.h"
#include "pogopo_power.h"
#include "pogopo_settings.h"
#include "pogopo_gameboy.h"
#include "pogopo_playdate.h"
#include "pogopo_menu.h"
#include "pogopo_startup.h"

#include <algorithm>
#include <array>
#include <cstdint>
#include <cstring>

#include "esp_chip_info.h"
#include "esp_flash.h"
#include "esp_log.h"
#include "esp_timer.h"
#include "freertos/FreeRTOS.h"
#include "freertos/task.h"

static const char* TAG = "app";

static pogopo::Graphics g_gfx;
static pogopo::Input g_input;
static pogopo::Haptics g_haptics;
static pogopo::Audio g_audio;
static pogopo::Storage g_storage;
static pogopo::Imu g_imu;
static pogopo::Power g_power;
static pogopo::Settings g_settings;
static pogopo::GameBoy g_gameboy;
static pogopo::AppManager g_app_manager(g_gfx, g_input, g_haptics, g_audio, g_storage, g_imu, g_power, g_settings);

static pogopo::demo::LauncherApp g_launcher_app;
static pogopo::demo::EmptyLibraryApp g_pogopo_library_app(
    "pogopo_library", "pogopo", "/pogopo/games", pogopo::menu::Art::Pogopo);
static pogopo::demo::GraphicsDemoApp g_graphics_app;
static pogopo::demo::InputMonitorApp g_input_app;
static pogopo::demo::HapticsLabApp g_haptics_app;
static pogopo::demo::AudioLabApp g_audio_app;
static pogopo::demo::WavPlayerApp g_wav_app;
static pogopo::demo::MotionLabApp g_motion_app;
static pogopo::demo::PowerStatusApp g_power_app;
static pogopo::demo::SettingsApp g_settings_app;
static pogopo::demo::PreferencesApp g_preferences_app;
static pogopo::demo::AboutApp g_about_app;
static pogopo::demo::GameBoyApp g_gameboy_app(g_gameboy);
static pogopo::demo::GameBoyBrowserApp g_gameboy_browser_app(g_gameboy_app);
static pogopo::demo::PogoDateApp g_pdsnake_app(
    pogopo::playdate::Game::PDSnake, "pogodate", "PogoDate Snake",
    "PDSNAKE 1.2", &g_gameboy);
static pogopo::demo::PogoDateApp g_celeste_app(
    pogopo::playdate::Game::Celeste, "pogodate_celeste", "Celeste Classic",
    "CELESTE CLASSIC 1.0.3", &g_gameboy);
static pogopo::demo::PogoDateApp g_pogodate_player(
    pogopo::playdate::Game::External, "pogodate_player", "Playdate SD Game",
    "SD PACKAGE", &g_gameboy);
static pogopo::demo::PogoDateBrowserApp g_pogodate_browser(g_pogodate_player);

namespace {

constexpr uint32_t kPowerOutroStartDelayMs = 200;

enum class PowerOutroPhase : uint8_t {
    Idle,
    Pending,
    Forward,
    Reverse,
    Complete,
};

PowerOutroPhase g_power_outro_phase = PowerOutroPhase::Idle;
bool g_power_outro_input_armed = false;
bool g_suppress_next_power_short = false;
size_t g_power_outro_frame = 0;
int64_t g_power_press_started_ms = 0;
int64_t g_power_outro_next_ms = 0;
std::array<uint8_t, pogopo::gfx::SharpDisplay::FRAMEBUFFER_SIZE> g_power_outro_underlay{};
const pogopo::OutroAnimation g_power_outro_animation;

bool power_outro_visible() {
    return g_power_outro_phase == PowerOutroPhase::Forward ||
           g_power_outro_phase == PowerOutroPhase::Reverse ||
           g_power_outro_phase == PowerOutroPhase::Complete;
}

uint32_t power_outro_forward_period(size_t frame) {
    return frame < pogopo::OutroAnimation::SLOW_LAST_FRAME
        ? pogopo::OutroAnimation::SLOW_FRAME_PERIOD_MS
        : pogopo::OutroAnimation::FAST_FRAME_PERIOD_MS;
}

uint32_t power_outro_reverse_period(size_t frame) {
    return frame > pogopo::OutroAnimation::SLOW_LAST_FRAME
        ? pogopo::OutroAnimation::FAST_FRAME_PERIOD_MS
        : pogopo::OutroAnimation::SLOW_FRAME_PERIOD_MS;
}

bool show_power_outro_frame(size_t frame) {
    const esp_err_t error = g_power_outro_animation.show(
        g_gfx, frame, g_power_outro_underlay.data(),
        g_power_outro_underlay.size());
    if (error != ESP_OK) {
        ESP_LOGE(TAG, "Power Outro frame %u failed: %s",
                 static_cast<unsigned>(frame + 1), esp_err_to_name(error));
        return false;
    }
    return true;
}

void restore_power_outro_underlay() {
    g_gfx.display().load_framebuffer(g_power_outro_underlay.data(),
                                     g_power_outro_underlay.size());
    g_gfx.presentFull();
    g_app_manager.endPowerOverlay();
    g_power_outro_phase = PowerOutroPhase::Idle;
    g_power_outro_frame = 0;
}

void cancel_power_outro(bool restore_underlay) {
    if (power_outro_visible()) {
        if (restore_underlay) {
            restore_power_outro_underlay();
        } else {
            g_app_manager.endPowerOverlay();
            g_power_outro_phase = PowerOutroPhase::Idle;
            g_power_outro_frame = 0;
        }
    } else {
        g_power_outro_phase = PowerOutroPhase::Idle;
    }
    g_suppress_next_power_short = false;
}

void begin_power_outro(int64_t now_ms) {
    if (!g_power_outro_animation.valid()) {
        ESP_LOGE(TAG, "Power Outro asset size mismatch: %u bytes",
                 static_cast<unsigned>(g_power_outro_animation.embeddedSize()));
        g_power_outro_phase = PowerOutroPhase::Idle;
        return;
    }

    g_app_manager.beginPowerOverlay();
    const uint8_t* framebuffer = g_gfx.display().framebuffer();
    if (framebuffer) {
        std::memcpy(g_power_outro_underlay.data(), framebuffer,
                    g_power_outro_underlay.size());
    }
    g_power_outro_frame = 0;
    g_power_outro_phase = PowerOutroPhase::Forward;
    g_suppress_next_power_short = true;
    show_power_outro_frame(g_power_outro_frame);
    g_power_outro_next_ms = now_ms + power_outro_forward_period(g_power_outro_frame);
    ESP_LOGI(TAG, "Power Outro started");
}

bool consume_suppressed_power_short() {
    if (!g_suppress_next_power_short) return false;
    g_suppress_next_power_short = false;
    ESP_LOGI(TAG, "Power short event suppressed after Outro hold");
    return true;
}

void update_power_outro(int64_t now_ms) {
    const bool button_down = g_power.buttonDown();
    if (!g_power_outro_input_armed) {
        if (!button_down) g_power_outro_input_armed = true;
        return;
    }

    if (g_power_outro_phase == PowerOutroPhase::Idle) {
        if (button_down) {
            g_power_outro_phase = PowerOutroPhase::Pending;
            g_power_press_started_ms = now_ms;
        }
        return;
    }

    if (g_power_outro_phase == PowerOutroPhase::Pending) {
        if (!button_down) {
            g_power_outro_phase = PowerOutroPhase::Idle;
        } else if (now_ms - g_power_press_started_ms >= kPowerOutroStartDelayMs) {
            begin_power_outro(now_ms);
        }
        return;
    }

    if (g_power_outro_phase == PowerOutroPhase::Complete) {
        if (!button_down) {
            g_power_outro_phase = PowerOutroPhase::Reverse;
            g_power_outro_next_ms =
                now_ms + power_outro_reverse_period(g_power_outro_frame);
        }
        return;
    }

    if (g_power_outro_phase == PowerOutroPhase::Forward) {
        if (!button_down) {
            g_power_outro_phase = PowerOutroPhase::Reverse;
            g_power_outro_next_ms =
                now_ms + power_outro_reverse_period(g_power_outro_frame);
            ESP_LOGI(TAG, "Power Outro reversing from frame %u",
                     static_cast<unsigned>(g_power_outro_frame + 1));
            return;
        }

        while (now_ms >= g_power_outro_next_ms &&
               g_power_outro_frame + 1 < pogopo::OutroAnimation::FRAME_COUNT) {
            ++g_power_outro_frame;
            if (!show_power_outro_frame(g_power_outro_frame)) {
                cancel_power_outro(true);
                return;
            }
            g_power_outro_next_ms += power_outro_forward_period(g_power_outro_frame);
        }
        if (g_power_outro_frame + 1 >= pogopo::OutroAnimation::FRAME_COUNT) {
            g_power_outro_phase = PowerOutroPhase::Complete;
            ESP_LOGI(TAG, "Power Outro complete; waiting for shutdown event");
        }
        return;
    }

    // Releasing after a visible hold always walks the exact supplied frames
    // backwards. Re-pressing during the rollback resumes from the same frame.
    if (button_down) {
        g_power_outro_phase = PowerOutroPhase::Forward;
        g_suppress_next_power_short = true;
        g_power_outro_next_ms =
            now_ms + power_outro_forward_period(g_power_outro_frame);
        return;
    }

    while (now_ms >= g_power_outro_next_ms) {
        if (g_power_outro_frame == 0) {
            restore_power_outro_underlay();
            ESP_LOGI(TAG, "Power Outro cancelled and restored");
            return;
        }
        --g_power_outro_frame;
        if (!show_power_outro_frame(g_power_outro_frame)) {
            cancel_power_outro(true);
            return;
        }
        g_power_outro_next_ms += power_outro_reverse_period(g_power_outro_frame);
    }
}

esp_err_t start_graphics() {
    pogopo::Graphics::Config config;
    config.sck_io = board::LCD_SCK;
    config.mosi_io = board::LCD_MOSI;
    config.cs_io = board::LCD_CS;
    config.disp_io = -1;
    config.extmode_io = -1;
    // Same clock that was stable in the Arduino/Adafruit_SharpMem build.
    // At 2 MHz a full 400x240 transfer alone took about 49 ms.
    config.clock_hz = 14000000;
    config.enable_vcom_task = true;
    config.vcom_period_ms = 500;
    config.vcom_task_priority = 4;
    config.vcom_task_core = 0;
    return g_gfx.begin(config);
}

esp_err_t start_haptics() {
    pogopo::Haptics::Config config;
    config.motor_io = board::VIBRO;
    config.active_high = true;
    config.task_priority = 4;
    config.task_core = 0;
    const esp_err_t err = g_haptics.begin(config);
    if (err == ESP_OK) g_haptics.setEnabled(g_settings.hapticsEnabled());
    return err;
}


esp_err_t start_audio() {
    pogopo::Audio::Config config;
    config.dout_io = board::AUDIO_DOUT;
    config.bclk_io = board::AUDIO_BCLK;
    config.lrck_io = board::AUDIO_LRCK;
    config.sample_rate = 32768;
    config.master_volume = g_settings.volume();
    // Match the stable Arduino Game Boy I2S path.
    config.dma_desc_num = 12;
    config.dma_frame_num = 512;
    config.render_frames = 512;
    config.realtime_buffer_frames = 4096;
    config.task_priority = 8;
    config.task_stack = 8192;
    config.task_core = 0;
    const esp_err_t err = g_audio.begin(config);
    if (err == ESP_OK) g_audio.setEnabled(g_settings.audioEnabled());
    return err;
}


esp_err_t start_gameboy() {
    pogopo::GameBoy::Config config;
    config.internal_rom_arena_bytes = 128U * 1024U;
    config.internal_rom_arena_min_bytes = 32U * 1024U;
    // Reserve at least a 112 KiB contiguous arena on the current board. When
    // PogoDate starts, its 96 KiB native screen borrows this block and still
    // leaves roughly 16 KiB contiguous plus the rest of the internal heap.
    config.internal_rom_headroom_bytes = 96U * 1024U;
    config.internal_rom_limit = 256U * 1024U;
    config.save_flush_interval_ms = 0; // Flush on exit/power-off, never mid-frame.
    config.requested_cache_pages = 8;
    // The Sharp frontend can present about 30 full scaled frames per second.
    // Skip only Peanut's expensive LCD drawing on alternate frames while the
    // CPU/APU still emulate every 59.7 Hz Game Boy frame.
    config.peanut_frame_skip = true;
    config.display_divider = 1;
    config.dither = true;
    config.task_priority = 6;
    config.task_core = 1;
    config.task_stack = 8192;
    config.audio_task_priority = 7;
    config.audio_task_core = 0;
    config.audio_task_stack = 4096;
    return g_gameboy.begin(g_audio, config);
}

esp_err_t start_storage() {
    pogopo::Storage::Config config;
    config.clk_io = board::SD_CLK; config.cmd_io = board::SD_CMD;
    config.d0_io = board::SD_D0; config.d1_io = board::SD_D1;
    config.d2_io = board::SD_D2; config.d3_io = board::SD_D3;
    config.mount_point = "/sdcard";
    config.max_files = 16;
    return g_storage.begin(config);
}

esp_err_t start_imu() {
    pogopo::Imu::Config config;
    config.bus = i2c_bus_handle(); config.address = 0x68;
    config.interrupt_io = board::IMU_INT; config.sample_period_ms = 20;
    // Keep Core 1 for input + emulator. BMI270 comfortably fits on Core 0
    // underneath the blocking priority-8 I2S writer.
    config.task_core = 0;
    return g_imu.begin(config);
}

esp_err_t start_power() {
    pogopo::Power::Config config;
    config.bus = i2c_bus_handle(); config.charger_address = 0x6B;
    config.power_button_io = board::POWER_BUTTON;
    config.charger_int_io = board::CHARGER_INT;
    config.battery_measure_io = board::BAT_MEAS;
    config.battery_gate_io = board::BAT_GATE;
    config.short_press_min_ms = 60;
    // 200 ms distinguishes a tap from a hold. Outro then reaches human frame
    // 13 at 10 FPS and frame 25 at about 15 FPS before this event is emitted.
    config.shutdown_hold_ms = 2220;
    config.task_core = 0;
    return g_power.begin(config);
}

void draw_power_message(const char* title, const char* line1, const char* line2) {
    auto& canvas = g_gfx.canvas();
    g_gfx.set_clip({0, 0, g_gfx.width(), g_gfx.height()});
    canvas.clear_clip(pogopo::gfx::WHITE);
    canvas.draw_rect(16, 18, 368, 204, pogopo::gfx::BLACK);
    pogopo::menu::PogoFont::drawText(canvas, 42, 36, title,
                                     pogopo::menu::FontFace::Italic22);
    canvas.draw_line(34, 74, 366, 74, pogopo::gfx::BLACK);
    pogopo::menu::PogoFont::drawText(canvas, 37, 93, line1,
                                     pogopo::menu::FontFace::Regular14);
    pogopo::menu::PogoFont::drawText(canvas, 37, 119, line2,
                                     pogopo::menu::FontFace::Regular14);
    pogopo::menu::PogoFont::drawText(canvas, 37, 172,
                                     "GPIO17 / BQ24295 BATFET",
                                     pogopo::menu::FontFace::Italic14);
    g_gfx.reset_clip();
    g_gfx.present();
}

void handle_power_event(const pogopo::power::Event& event) {
    if (event.type == pogopo::power::EventType::ShortPress) {
        if (consume_suppressed_power_short()) return;
        g_app_manager.toggleSystemMenu();
        return;
    }

    if (event.type == pogopo::power::EventType::UsbBlocked) {
        cancel_power_outro(true);
        g_haptics.play(pogopo::HapticEffect::Alert);
        g_audio.play(pogopo::AudioEffect::Error);
        draw_power_message("USB CONNECTED", "UNPLUG TYPE-C TO POWER OFF", "RELEASE POWER BUTTON");
        g_power.waitForRelease(8000);
        g_app_manager.invalidate();
        return;
    }

    // The Power task emits ShutdownRequested only after the final 25th frame
    // deadline. Force that white terminal frame if the GUI loop was delayed by
    // an SD/I2C operation, then keep it visible until QON is safely released.
    if (g_power_outro_frame + 1 < pogopo::OutroAnimation::FRAME_COUNT) {
        g_power_outro_frame = pogopo::OutroAnimation::FRAME_COUNT - 1;
        show_power_outro_frame(g_power_outro_frame);
    }
    g_power_outro_phase = PowerOutroPhase::Complete;
    g_haptics.play(pogopo::HapticEffect::Heavy);
    g_gameboy.flushSave();
    g_audio.play(pogopo::AudioEffect::Confirm);
    g_power.waitForRelease(8000); // QON must be released or the charger can wake again immediately.
    vTaskDelay(pdMS_TO_TICKS(120));
    g_audio.stopAll();

    // Return the software framebuffer and the physical panel to white before
    // BATFET is disabled. The panel naturally relaxes to reflective white when
    // its rails collapse, so this also matches the first frame of the startup.
    g_gfx.display().clear(pogopo::gfx::WHITE);
    const esp_err_t lcd_clear_error = g_gfx.display().clear_lcd_hw();
    if (lcd_clear_error != ESP_OK) {
        ESP_LOGW(TAG, "LCD pre-shutdown clear failed: %s",
                 esp_err_to_name(lcd_clear_error));
    }

    const esp_err_t err = g_power.enterShipMode();
    if (err != ESP_OK) {
        draw_power_message("POWER ERROR", esp_err_to_name(err), "PRESS RESET OR TRY AGAIN");
    }
    while (true) vTaskDelay(pdMS_TO_TICKS(1000));
}

esp_err_t start_input() {
    pogopo::Input::Config config;
    config.bus = i2c_bus_handle();
    config.address = 0x20;
    config.interrupt_io = board::TCA9555_INT;
    config.active_low = true;
    config.poll_period_ms = 4;
    config.debounce_samples = 3;
    config.repeat_delay_ms = 450;
    config.repeat_period_ms = 100;
    config.long_press_ms = 700;
    config.task_priority = 7;
    config.task_core = 1;
    return g_input.begin(config);
}

void discard_startup_input() {
    pogopo::input::Event event;
    while (g_input.nextEvent(event, 0)) {}
    g_input.consumePressedMask();
    g_input.consumeReleasedMask();
    g_input.consumeRepeatMask();
    g_input.consumeLongPressMask();
}

bool wait_startup_frame(TickType_t& next_frame,
                        bool allow_dismiss,
                        bool& input_armed,
                        bool& power_armed,
                        const char*& dismissed_by) {
    next_frame += pdMS_TO_TICKS(pogopo::StartupAnimation::FRAME_PERIOD_MS);

    while (true) {
        const bool outro_was_visible = power_outro_visible();
        update_power_outro(esp_timer_get_time() / 1000);
        const bool outro_owns_display = power_outro_visible();

        pogopo::input::Event input_event;
        while (g_input.nextEvent(input_event, 0)) {
            if (!allow_dismiss || outro_owns_display) continue;

            if (!input_armed) {
                if (g_input.heldMask() == 0) input_armed = true;
                continue;
            }
            if (input_event.type == pogopo::input::EventType::Pressed) {
                dismissed_by = pogopo::input::button_name(input_event.button);
                return true;
            }
        }

        if (allow_dismiss && !input_armed && g_input.heldMask() == 0) {
            input_armed = true;
        }

        pogopo::power::Event power_event;
        while (g_power.nextEvent(power_event, 0)) {
            if (power_event.type == pogopo::power::EventType::ShortPress) {
                if (consume_suppressed_power_short()) continue;
                if (allow_dismiss && power_armed) {
                    dismissed_by = "POWER";
                    return true;
                }
                continue;
            }

            handle_power_event(power_event);
            // USB-blocked handling can wait for release and draw its own card.
            // Restart the animation deadline instead of racing through frames.
            next_frame = xTaskGetTickCount() +
                         pdMS_TO_TICKS(pogopo::StartupAnimation::FRAME_PERIOD_MS);
        }

        if (power_outro_visible()) {
            next_frame = xTaskGetTickCount() +
                         pdMS_TO_TICKS(pogopo::StartupAnimation::FRAME_PERIOD_MS);
            vTaskDelay(std::max<TickType_t>(pdMS_TO_TICKS(4), 1));
            continue;
        }

        if (outro_was_visible) {
            // A completed rollback has just restored the interrupted startup
            // frame. Give it a full 100 ms instead of catching up instantly.
            next_frame = xTaskGetTickCount() +
                         pdMS_TO_TICKS(pogopo::StartupAnimation::FRAME_PERIOD_MS);
        }

        if (allow_dismiss && !power_armed && !g_power.buttonDown()) {
            power_armed = true;
        }

        const TickType_t now = xTaskGetTickCount();
        const int32_t ticks_left = static_cast<int32_t>(next_frame - now);
        if (ticks_left <= 0) {
            // Never burst through several frames to catch up after a delayed
            // LCD transfer or a blocking power/USB notification.
            next_frame = now;
            return false;
        }

        const TickType_t poll_ticks = pdMS_TO_TICKS(4);
        vTaskDelay(std::min<TickType_t>(static_cast<TickType_t>(ticks_left),
                                       std::max<TickType_t>(poll_ticks, 1)));
    }
}
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
extern "C" void app_main(void) {
    esp_chip_info_t chip = {};
    esp_chip_info(&chip);
    uint32_t flash_size = 0;
    ESP_ERROR_CHECK(esp_flash_get_size(nullptr, &flash_size));

    ESP_LOGI(TAG, "pogopoOS2.0 STEP13.5.3 POGODATE STABILITY");
    ESP_LOGI(TAG, "ESP32-S3 cores=%d rev=%d flash=%u MB",
             chip.cores, chip.revision,
             static_cast<unsigned>(flash_size / (1024 * 1024)));

    ESP_ERROR_CHECK(g_settings.begin());
    ESP_ERROR_CHECK(i2c_bus_init());
    i2c_scan();
    run_peripheral_tests();

    // Reserve the adaptive ROM/cache arena before the display framebuffer,
    // DMA transfer buffer and background task stacks fragment internal RAM.
    ESP_ERROR_CHECK(start_audio());
    ESP_ERROR_CHECK(start_gameboy());
    ESP_ERROR_CHECK(start_graphics());
    ESP_ERROR_CHECK(start_haptics());
    ESP_ERROR_CHECK(start_input());

    const esp_err_t sd_err = start_storage();
    if (sd_err != ESP_OK) ESP_LOGW(TAG, "SD unavailable; WAV player will show instructions: %s", esp_err_to_name(sd_err));
    const esp_err_t imu_err = start_imu();
    if (imu_err != ESP_OK) ESP_LOGW(TAG, "BMI270 unavailable: %s", esp_err_to_name(imu_err));
    ESP_ERROR_CHECK(start_power());

    // Stable pogopoOS1.0 split: Core 1 runs high-priority input + emulator;
    // Core 0 runs high-priority I2S and low-priority GUI/Sharp presentation.
    // PDZ imports and termination callbacks can nest several Lua/C frames.
    // Hardware high-water logs reached 108 bytes with the old 8 KiB stack.
    if (xTaskCreatePinnedToCore(os_task, "pogopo_os", 16384, nullptr, 1, nullptr, 0) != pdPASS) {
        ESP_LOGE(TAG, "Could not create pogopoOS task");
    }

    start_system_tasks();
    ESP_LOGI(TAG, "STEP13.5.3 system tasks started: startup animation pending");
}

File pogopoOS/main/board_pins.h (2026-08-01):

#pragma once
namespace board {
constexpr int I2C_SDA = 8;
constexpr int I2C_SCL = 9;
constexpr int IMU_INT = 18;
constexpr int TCA9555_INT = 21;
constexpr int LCD_SCK = 12;
constexpr int LCD_MOSI = 11;
constexpr int LCD_CS = 14;
constexpr int AUDIO_DOUT = 38;
constexpr int AUDIO_BCLK = 39;
constexpr int AUDIO_LRCK = 40;
constexpr int SD_D0 = 5;
constexpr int SD_D1 = 4;
constexpr int SD_D2 = 16;
constexpr int SD_D3 = 15;
constexpr int SD_CLK = 6;
constexpr int SD_CMD = 7;
constexpr int VIBRO = 3;
constexpr int RGB_LED = 48;
constexpr int POWER_BUTTON = 17;
constexpr int CHARGER_INT = 41;
constexpr int BAT_MEAS = 1;
constexpr int BAT_GATE = 2;
}

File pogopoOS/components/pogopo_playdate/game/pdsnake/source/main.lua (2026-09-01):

import "CoreLibs/object"
import "CoreLibs/timer"
import "CoreLibs/graphics"
import "store"
import "fonts"
import "icons"
import "sfx"
import "layout"
import "settings"
import "screen"
import "meta"
import "stats"
import "scenes"

local settings <const> = settings
local stats <const> = stats
local scenes <const> = scenes
local meta <const> = meta

function init()
	settings.load()
	stats.load()

	local menu = playdate.getSystemMenu()
	menu:addCheckmarkMenuItem("play sfx", settings.playSfx, settings.toggleSfx)
	menu:addCheckmarkMenuItem("dark mode", settings.darkMode, settings.toggleDarkMode)
	menu:addCheckmarkMenuItem("batt. saver", settings.batterySaver, settings.toggleBatterySaver)
	scenes.switchTo(scenes.mainMenu)
end

function playdate.update()
	playdate.timer.updateTimers()

	scenes.update()

	if meta.isDebug then
		playdate.drawFPS(screen.width - 24, 12)
	end
end

function playdate.gameWillTerminate()
	stats.addTimePlayed(playdate.getCurrentTimeMilliseconds())
	stats.save()
end

init()

function playdate.serialMessageReceived(message)
	if not meta.isDebug then
		return
	end

	print("Received message: " .. message)

	if string.find(message, "scene:") == 1 then
		local scene = string.sub(message, 7)
		print("Switching to " .. scene .. " from serialMessageReceived")
		local newScene = scenes[scene]

		if newScene == nil then
			print("Scene " .. scene .. " does not exist")
			return
		end

		scenes.switchTo(newScene)
	end
end

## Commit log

2026-07-31 add button events and async haptics
2026-07-31 add GUI and application framework
2026-07-31 add SD WAV, BMI270 and power management
2026-07-31 fix: smooth Motion Lab visuals and tune sound levels
    [audio.cpp]
2026-07-31 fix: improve frame compatibility
    FPS improved, but audio crackling and periodic frame drops remain.
    [app_main.cpp]
2026-07-31 fix: restore stable audio and core scheduling
    Small internal-RAM ROMs now reach full speed, but PSRAM-backed games remain slow and can trigger audio underruns, watchdog faults and stuck input after I2C read failures.
    [app_main.cpp, audio.cpp, audio.h]
2026-07-31 fix: experiment with PSRAM scheduling and adaptive audio
    The experiment remains unsuccessful: Mario and Kirby can fall below 20 emulated FPS, Kirby presents at roughly 10-15 FPS, and adaptive audio stretching changes pitch and sounds noticeably distorted.
    [app_main.cpp, audio.cpp, audio.h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]
2026-08-01 fix: restore fixed-rate audio and prioritize internal ROM
    Pack four Game Boy shades into 2 bpp buffers, restore ordered dithering, and reserve a 256 KiB internal-ROM arena for Kirby. Remove adaptive playback-rate compensation and automatic PSRAM frame skipping while retaining the input and watchdog safeguards from STEP9.3.
    [app_main.cpp, audio.cpp, audio.h]
2026-08-01 fix: achieve full-speed emulation and stable 30 FPS output
    Restores fixed-pitch audio, 14 MHz Sharp transfers, ordered dithering, packed internal framebuffers and adaptive ROM caching. Mario and Kirby now run reliably at full emulation speed with approximately 30 FPS LCD presentation and no observed regressions.
    [app_main.cpp, audio.cpp, board_pins.h]
2026-08-01 fix: add power quick menu and clean LCD shutdown
    Clear the Sharp Memory LCD before entering ship mode, soften the UI tick, and open a suspend-aware quick menu on short Power presses. Add volume, Settings and Home actions, preserve the Start+B fast exit, and reserve additional application slots for custom games.
    [app_main.cpp, audio.cpp, power.cpp]
2026-08-01 fix: add complete ASCII glyph coverage
    Add all printable ASCII punctuation to the system 5x7 font so Game Boy ROM filenames, selection arrows and future game interfaces no longer render ordinary characters as unknown-symbol boxes.
2026-08-04 add PDSnake Lua runtime
    The first build failed because of an invalid CMake command in the Playdate component.
    [partitions.csv]
2026-08-05 fix: Celeste clamp build error
    Celeste now compiles correctly with both float and double Lua builds.
2026-08-05 stabilize SD package browser
    Celeste was detected, but launching remained stuck in a repeating loading loop.
    [app_main.cpp, storage.cpp]
2026-08-05 add file API and 50 FPS mode
    Frogger now loads from SD, but stops on the missing drawRotated image method.
    [app_main.cpp]
2026-08-05 fix: add button name compatibility
    Frogger still failed on string btnp input, while the 50 FPS Celeste test ran too fast and retained animation stutter.
2026-08-05 improve PDX compatibility and frame pacing
    Celeste and Onebit Frogger now appear stable, while broader PDX support still requires testing and fixes.
    [app_main.cpp]
2026-08-09 add startup animation
    STEP12.0 adds a 111-frame boot animation with a looping ending before entering the launcher.
    [partitions.csv]
2026-08-09 fix: fix SharpBit animation linker symbols
    STEP12.1 fixes the startup animation link failure without changing its playback behavior.
    [app_main.cpp]
2026-08-09 fix: keep LCD black on shutdown
    STEP12.2 replaces the white hardware clear with a full black framebuffer before ship mode.
    [app_main.cpp]
2026-08-09 refresh startup animation and restore white shutdown
    STEP12.3 updates the SharpBit boot sequence to 122 frames and restores the stable white power-off screen.
2026-08-12 add short interactive startup pogopo intro
    STEP12.4 replaces the long intro with a 25-frame animation that loops until input and finishes with a short outro.
    [app_main.cpp]
2026-08-13 add first animated Pogopo menu revision
    STEP13.0 replaces the development launcher with the new animated Pogopo home menu, libraries and settings interface.
    [app_main.cpp]
2026-08-13 polish launcher and quick panel
    STEP13.1 improves menu spacing, console transitions, settings, ROM browsing and adds the Playdate-style Power quick panel.
2026-08-13 add interactive Power Outro
    STEP13.2 integrates the final Intro and Outro animations with clean tap-hold handling, reversible shutdown animation and quick-panel polish.
2026-08-13 fix: preserve Outro transparency
    STEP13.2.1 keeps the real alpha mask so transparent Outro pixels preserve the underlying menu or game instead of rendering black.
    [app_main.cpp]
2026-08-13 fix: remove white first Outro frame
    STEP13.2.2 skips the all-white first Outro frame so Power hold starts without a white flash.
    [app_main.cpp]
2026-08-18 expand PDX compatibility and add PFT fonts
    STEP11.5 adds real Playdate font rendering and broader graphics, timer, sprite and audio support validated with Onebit Frogger and Godspeed.
2026-08-18 fix: correct colors and expose partial LCD updates
    STEP11.5.1 fixes Playdate color mapping, optimizes the 400x240 Sharp path and adds dirty-row transfer diagnostics.
    [app_main.cpp]
2026-08-18 expand Lua PDX compatibility
    STEP11.6 adds broader Playdate APIs and validates the runtime with Duel Of Shadows through an 1800-frame zero-error stress test.
2026-08-23 fix: add Noble focus and correct PFT stereo decoding
    STEP11.6.2 adds lockFocus support, fixes aligned PFT glyph parsing and stereo PDA decoding, and prevents slow Lua frames from starving the watchdog.
    [app_main.cpp]
2026-08-23 add dither patterns and full frameTimer support
    STEP11.6.3 implements real Playdate dither patterns and completes callback and value frame-timer overloads validated with Maze and Duel Of Shadows.
2026-08-23 extend Maze and Duel gameplay compatibility
    STEP11.6.4 adds the remaining Noble, accelerometer, sprite and draw-offset support needed for Maze gameplay and Duel Of Shadows boss-room progression.
2026-08-23 improve Maze Gridview and motion input
    STEP11.6.5 enables Maze's bundled Gridview, corrects BMI270 Playdate-axis mapping and adds START as an A-button alias for PDX games.
    [app_main.cpp, playdate_apps.h]
2026-08-23 fix: correct Maze hole flow and Duel portal detection
    STEP11.6.6 adds complete image-scaling and draw-mode support, fixes BMI270 Z-axis mapping and separates overlap queries from collision response.
    [app_main.cpp]
2026-08-23 fix PDX input axes and optimize rendering
    STEP11.6.7 corrects button and BMI270 axes, pools transient Maze frames, adds native Duel tilemap rendering and improves Playdate prompt compatibility.
    [app_main.cpp]
2026-08-23 fix: restore stable PDX input mapping
    STEP11.6.8 rolls back the broad button and BMI270 X-axis inversions from STEP11.6.7 while preserving its performance and compatibility improvements.
    [app_main.cpp]
2026-08-23 fix: correct Maze controls and pool completion frames
    STEP11.6.9 adds Maze-specific horizontal and Y-axis input correction and lowers the reusable PSRAM frame threshold to cover Level Complete images.
    [app_main.cpp]
2026-08-23 fix: polish Maze completion and Duel boss fight
    STEP11.6.10 optimizes sparse Maze completion rendering, removes its START-to-A conflict and fixes Duel scaled-sprite orientation, frame sizing and collision response.
    [app_main.cpp]
2026-08-23 extend Pulp graphics and audio runtime
    STEP11.6.14 adds the graphics and sound-clock APIs required by Pulp packages and validates WOOD through a 1800-frame zero-error gameplay stress test.
    [app_main.cpp]
2026-08-24 fix: implement responder stack for Pulp controls
    STEP11.6.15 routes button events through Playdate input handlers to global callbacks so Pulp games like WOOD receive A, B and D-pad controls correctly.
    [app_main.cpp]
2026-08-24 fix: correct Hillslide timers and compact PDT frames
    [app_main.cpp]
2026-08-24 fix: correct camera draw-offset rendering
    [app_main.cpp]
2026-09-01 fix: make resources coroutine-safe and improve argument compatibility
    [app_main.cpp]
2026-09-01 fix: improve audio overlap and scene transition safety
    [app_main.cpp, audio.cpp, audio.h]
2026-09-01 fix: restore visual effects, ADPCM decoding and high-speed SDMMC
    [app_main.cpp, storage.cpp]
2026-09-01 Integrate Playdate runtime with STEP13 menu
    [partitions.csv]
2026-09-03 fix fps up pogodate
    [app_main.cpp]
2026-09-03 rework frame generation
2026-09-03 fix last fast-RAM commit
    [app_main.cpp]
2026-09-03 next fix, up size RAM to 96kb
    [app_main.cpp]
2026-09-07 fix: update normal font and open playdate games
    [app_main.cpp]
2026-09-23 Restructure repository around Pogopo hardware and firmware
    [partitions.csv, pogopo.step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]
